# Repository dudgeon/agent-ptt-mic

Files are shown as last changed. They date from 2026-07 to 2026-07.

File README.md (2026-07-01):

# Claude Code Companion Peripheral

A single USB-C peripheral, built on a Seeed Studio XIAO RP2040, that
enumerates — with no driver install — as both a USB HID keyboard and a USB
Audio Class microphone at the same time. Physical controls handle push-to-talk
microphone activation, an always-on latch, and the keystrokes Claude Code uses
for its permission/approval prompts.

## Status

Pre-hardware-arrival, breadboard-planning phase. The RP2040 board has been
ordered but hasn't shipped yet. See [`docs/STATUS.md`](docs/STATUS.md) for the
live progress tracker.

## Start here

- [`docs/SPEC.md`](docs/SPEC.md) — the full project specification: verbatim
  requirements from the project owner, locked decisions, open questions, pin
  map, and the milestone-by-milestone work plan. This is the single source of
  truth; there is no other record of these requirements.
- [`docs/STATUS.md`](docs/STATUS.md) — current progress against the milestone
  plan and open questions.
- [`CLAUDE.md`](CLAUDE.md) — quick orientation for a coding agent picking this
  project up.

## Repo layout

```
docs/       spec + status
firmware/   RP2040 firmware (Pico SDK + TinyUSB)
hardware/   BOM, wiring notes, breadboard/PCB assets
```

## Hardware

- **MCU:** Seeed Studio XIAO RP2040 ([product page](https://www.seeedstudio.com/XIAO-RP2040-v1-0-p-5026.html), [wiki](https://wiki.seeedstudio.com/XIAO-RP2040/))
- **Mic:** I2S MEMS breakout (SPH0645 recommended, not yet purchased)
- **Controls:** 5 momentary buttons + 1 latching switch (see `docs/SPEC.md` §8 for the pin map)

## Work plan

See `docs/SPEC.md` §12 for the full milestone breakdown (M1–M7). In short:
toolchain bring-up → HID-only → UAC2-only (synthetic tone) → composite
HID+UAC2 device (highest-risk step) → real mic → buttons/gating/LED →
freeze for custom PCB handoff.

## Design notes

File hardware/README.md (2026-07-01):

# Hardware

Breadboard phase — see `docs/SPEC.md` §7 (BOM) and §8 (pin map).

## Bill of materials

| Part | Status |
|---|---|
| Seeed Studio XIAO RP2040 | Ordered, not arrived |
| I2S MEMS mic (SPH0645 recommended) | Not yet purchased (OQ2) |
| 5× tactile momentary switches | Not yet purchased |
| 1× slide/toggle switch (always-stream latch) | Not yet purchased |
| Breadboard + jumper wires | Not yet purchased |
| Data-capable USB-C cable | Not yet purchased |

## Pin map

See `docs/SPEC.md` §8 for the full XIAO-pad-to-GPIO table and the
constraints driving it (consecutive-GPIO requirement for I2S BCLK/LRCLK,
active-low buttons via internal pull-ups, active-low onboard LEDs).

This directory will hold breadboard photos, wiring notes, and eventually
custom PCB design files once the Milestone 7 gate (`docs/SPEC.md` §12) is
reached — no PCB work before then.

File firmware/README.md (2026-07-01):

# Firmware

Empty for now — no toolchain has been installed or firmware written yet.
This directory is scaffolding for Milestone 1 onward (see `docs/SPEC.md` §12).

## Planned toolchain (OQ1, proposed default)

**Pico SDK (C) + TinyUSB**, per `docs/SPEC.md` §5 OQ1. This is where the
reference USB Audio Class examples live (`uac2_headset`, `audio_4_channel_mic`)
and gives direct control over the composite USB descriptor needed for M4.
Not yet explicitly re-confirmed by the project owner — flagged in
`docs/STATUS.md`.

## Setup (once OQ1 is confirmed)

1. Install the [Pico SDK](https://github.com/raspberrypi/pico-sdk) and the
   `arm-none-eabi` toolchain.
2. TinyUSB is vendored as a submodule of the Pico SDK — no separate install.
3. Project layout will follow the standard Pico SDK CMake structure
   (`CMakeLists.txt` + `pico_sdk_import.cmake` at this directory's root).

None of this requires the physical board to be in hand — only flashing and
enumeration testing (M1's gate onward) do.

## Milestone-to-code mapping (planned)

- `m1_blink/` — minimal blink to prove the toolchain and flashing process
- `m2_hid/` — HID keyboard only
- `m3_uac2/` — UAC2 mic only, synthetic sine tone
- `m4_composite/` — merged HID + UAC2 composite descriptor
- `m5_mic/` — real I2S mic via PIO
- `m6_controls/` — buttons, switch, gating logic, status LED

These don't exist yet; created as each milestone starts.

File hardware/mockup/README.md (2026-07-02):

# 3D mockup — integrated design, real component dimensions

Dimensionally representative assembly of the whole device: carrier PCB,
XIAO RP2040 module (header-mounted on the back, USB-C facing away into
the back shell), 5× Kailh Choc V1 switches + MBK-profile caps, PCM12SMTR
latch slide (knob through the right wall), an I2S mic breakout module
(front side), an addressable RGB LED (v2.1 — see
`docs/PHYSICAL_DESIGN_SPEC.md` §7 for why it's SMD again), and both shell
halves. Every envelope comes
from `../design_params.py` — the same values that drive the PCB and
enclosure, so the mockup can't silently disagree with them.

Render-color note: the PTT cap is shown orange purely so reviews can point
at it; the real build is all-blank caps per the minimalist decision.

## Files

- `mockup.py` — builds all parts, exports `output/mockup_assembly.step`
  (colored STEP; open in any CAD viewer) and `output/parts/*.stl`.
- `render.py` — shades the part meshes and writes `output/renders/*.png`:
  assembled front/rear iso, internals front/back, orthographic front view,
  exploded view.

```
python3 hardware/mockup/mockup.py && python3 hardware/mockup/render.py
```

Outputs are committed for review without tooling.

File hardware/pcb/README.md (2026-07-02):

# Carrier PCB — KiCad project

2-layer carrier board (44 × 104 mm) for the handheld device: hosts the XIAO
RP2040 module (**pre-soldered/header SKU**, mounted on the BACK via its own
header pins, USB-C facing away into the back shell), 5× Kailh Choc V1
keyswitches, the PCM12SMTR side-actuated latch slide, an I2S mic
**breakout module** (front side, THT header), an **addressable RGB LED**
(WS2812B/SK6812-style — the one deliberately-reintroduced SMD part, see
below) + THT passives — every other active part is through-hole/header-
mount, hand-solderable with a plain iron (2026-07-02 revision; see
`docs/PHYSICAL_DESIGN_SPEC.md` §7 for why). Net/pin assignments follow
`docs/SPEC.md` §8 plus the status LED on spare D10/GPIO3 — the full
netlist table is in `../BOM.md`.

**Why the LED is SMD again:** Geoff asked for a true RGB status LED. A
discrete (non-addressable) RGB LED needs 3 independent GPIOs; the locked
pin map only has 2 spares. An addressable LED needs just 1 data pin, so
it's the only option that fits — still hand-solderable (large gull-wing
pads), just not through-hole.

## Files

- `generate_pcb.py` — the source of truth. Regenerates the board file from
  `../design_params.py`. Run `python3 hardware/pcb/generate_pcb.py` from the
  repo root after changing any dimension or position.
- `companion_carrier.kicad_pcb` — generated output (committed so it can be
  reviewed/opened without running anything).
- `companion_carrier.kicad_pro` — project file.

## Status: placed + netlisted, NOT routed

Deliberate scope cut, not an oversight: every footprint is placed and every
pad carries its net (open the board in KiCad and the full ratsnest appears),
but copper traces are not laid. Hand-computing trace geometry outside KiCad
means no live DRC, which is how you ship shorts. Routing this board in an
interactive KiCad session is ~30 minutes of work: all signals are slow
single-ended GPIO, the only mild care point is keeping the three I2S lines
short-ish and away from the LED data line. GND zones on both layers are
declared (fill them with `B` in pcbnew).

There is intentionally no `.kicad_sch`: the circuit is 17 components with a
one-net-per-switch topology, fully specified by the netlist table in
`../BOM.md` and encoded on the pads here. Drawing a schematic in KiCad from
that table is mechanical; hand-writing `.kicad_sch` s-expressions without
KiCad available to validate them is where errors would creep in.

## Before fabrication — VERIFY list

Footprint geometry here is derived from datasheets/community footprints at
design time. Before generating gerbers:

1. **XIAO header pin holes** — drill/pad size (currently 1.0mm drill,
   1.8mm pad) must fit the actual presoldered pin diameter; check against
   the physical board, not just a generic 0.1" header assumption.
2. **XIAO pin order** — the module is placed USB-down, back side; the
   pad-to-net map in `generate_pcb.py` encodes the 180° rotation of
   Seeed's USB-up pinout drawing. Sanity-check against a physical board
   before soldering.
3. **XIAO standoff/pin length** — `design_params.py XIAO_MODULE_STANDOFF`
   (6.0mm) is an estimate for how far the module hangs off the carrier;
   measure the real pin length before finalizing the enclosure thickness.
4. **PCM12SMTR land pattern** — approximated; pull the real drawing from the
   C&K datasheet.
5. **Mic breakout footprint** — `MIC_BRK_L/W` and pin pitch are
   approximate; measure the physical breakout (Adafruit #3421 or
   equivalent) and adjust before finalizing the front-wall window size.
6. **Choc contact-pin handedness** — pin 2 at (5.0, −3.8) assumes the common
   variant; check against a physical switch.
7. Run DRC after routing, obviously.

## Coordinate convention

Board space: X = 0 at the board centreline, Y = 0 at the top (mic) edge,
+Y toward the USB-C end. Sheet offset (60, 30) mm. All positions come from
`../design_params.py` — edit there, not here.

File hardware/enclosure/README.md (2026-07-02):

# Enclosure — FDM-printable handheld shell

Two printed parts (CadQuery source: `enclosure.py`, all dimensions from
`../design_params.py`):

- **Front shell** — front face + full-depth perimeter walls. Openings: one
  shared macropad-style cutout for the 2×2 keystroke cluster, a separate
  framed opening for the PTT key, a windowed opening sized to the mic
  breakout module and a ⌀3.4mm LED window at the top, latch-slide slot in
  the right wall, USB-C opening in the bottom wall (now much deeper in Z,
  since the module hangs off the back — see below). Four internal bosses
  locate and seat the PCB.
- **Back lid** — flush inset panel with four spacer bosses. M2 × 16
  self-tapping screws enter from the back: lid → spacer → PCB → front boss.

Envelope: **49.2 × 109.2 × 22.6 mm** — palm-sized vertical remote, thicker
than the original 14.3mm estimate. That growth is a direct, deliberate
consequence of the 2026-07-02 mounting revision: the XIAO Geoff actually
ordered is the pre-soldered/header SKU, which mounts on the carrier's BACK
via its own header pins rather than sitting flush — the `BACK_GAP` needed
to clear the module (module standoff + PCB + USB-C) grew from 3.2mm to
11.5mm. See `docs/PHYSICAL_DESIGN_SPEC.md` §7. The grip zone (blank lower
third of the front face) is where the XIAO hangs off the back; thumb lands
on PTT at bottom-centre with the 2×2 cluster above it.

## Regenerating

```
python3 hardware/enclosure/enclosure.py   # writes output/*.stl + *.step
```

`output/` is committed so the parts can be reviewed/printed without running
anything.

## Print notes

- Front shell prints face-down: clean front surface, walls/bosses grow
  upward, no supports; the USB and slide openings in the walls are small
  self-supporting bridges.
- Lid prints flat, boss side up.
- Sharp front edges: the parametric edge-break fillet is currently skipped
  (the CAD kernel refuses the fillet where opening rims meet the corner
  radii — logged at build time). For the fit-check print, break edges in
  the slicer or with sandpaper; a proper chamfer is a v2 modelling task.
- Flat, uninterrupted faces above/below/beside each opening are deliberate:
  they're the UV-print label zones per `docs/PHYSICAL_DESIGN_SPEC.md` §1.

## Fit-check before trusting the model

First print should verify: keycap free travel in the openings (0.5 mm/side
clearance), USB-C plug insertion depth through the 2.6 mm wall, slide-knob
reach through the right wall, and M2 self-tap engagement in the ⌀1.7 pilots.
Adjust `design_params.py` clearances and regenerate rather than editing
geometry by hand.

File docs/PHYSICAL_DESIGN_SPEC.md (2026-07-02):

# Physical Design Spec — PCB Breakout, Enclosure, and 3D Mockup

**Status:** Requirements captured 2026-07-01; first full design pass executed
2026-07-02 — see §7 for what was built and where the implementation deviated
from the proposals below.
**Scope note:** This track was explicitly requested by Geoff ahead of the
`docs/SPEC.md` §12 Milestone 7 gate ("no PCB work until the breadboard design
is functionally locked"). Per that document's own tie-breaker rule — a direct
instruction from Geoff overrides a locked decision — this is intentional and
tracked here rather than silently overriding §3.4. The breadboard milestone
plan (M1–M6) is unaffected and continues in parallel; this document covers a
second, concurrent track: selecting exact components and designing the
custom carrier PCB + handheld enclosure + a dimensionally-accurate 3D mockup.

This document is the handoff input for that second track. It captures the
decisions gathered directly from Geoff plus the engineering conclusions that
follow from them. **It does not contain finished component picks, PCB
layout, or 3D files** — those are the next session's deliverables (see
`docs/HANDOFF.md`).

---

## 1. Decisions gathered from Geoff (this session)

| Question | Answer |
|---|---|
| Form factor / mounting | **Handheld remote** — small enough to hold in one hand like a clicker, cable-tethered (not a desk puck, not keyboard/monitor-mounted). |
| Button tactile feel | **Mechanical keyswitches** — real switch mechanism with removable keycaps, not membrane/rubber-dome or bare SMD tactile buttons. |
| Enclosure fabrication | **3D printed, FDM** — desktop/service FDM printing, not resin/SLA, not laser-cut, not an off-the-shelf box. |
| Aesthetic / legends | **Minimalist** — clean, unlabeled surfaces. Geoff intends to add labels/graphics himself via **UV printing** onto the finished case after fabrication. The enclosure design must therefore leave flat, uninterrupted print-friendly surfaces near each control rather than integrating engraved/backlit legends. |

---

## 2. Engineering implications and proposed follow-ons [PROPOSED — confirm during next session or at the next checkpoint with Geoff]

These follow directly from the answers above but weren't asked explicitly —
flagging each rather than silently deciding.

### 2.1 Mechanical keyswitches in a handheld form factor → low-profile switch family
A **full-height Cherry MX-style switch** (~11mm switch body + ~7–8mm keycap
≈ 18–20mm stack height) makes for a thick, chunky handheld object — closer to
a game controller than a clicker. Given "handheld remote" was the explicit
form-factor choice, **low-profile mechanical switches** better satisfy both
answers at once:
- **Kailh Choc (PG1350, V1)** — ~11mm × 13.8mm footprint, ~2.6mm actuation
  travel, low-profile keycaps available (Choc/MBK caps), hot-swap sockets
  exist. Widely used in slim mechanical keyboards; well-documented KiCad
  footprints exist in community libraries.
- **Cherry MX Low Profile (RGB / Speed)** — same MX-compatible mount pattern
  as standard MX but ~11.9mm total height instead of ~18mm+; standard MX
  low-profile keycaps required (not interchangeable with full MX caps).
- **Recommendation for next session:** default to Kailh Choc V1 unless the
  next session's part-availability check favors Cherry MX Low Profile —
  Choc has the smaller footprint of the two, which matters more for a
  one-hand device.

### 2.2 The always-stream latch is a different control class than the 5 momentary buttons
A latching "always-stream" control shouldn't use a momentary keyswitch (it
would need firmware-side toggle logic and risks feeling wrong under the
thumb). Propose a small **mechanical slide or toggle switch** (e.g. C&K
sub-mini slide switch, or E-Switch EG-series toggle) as a genuinely distinct
part and physical affordance from the 5 keyswitches — so it's
unmistakable by feel alone which control is the latch.

### 2.3 Proposed control layout (handheld, one-hand operation)
No handedness preference was captured — proposing a **symmetric/ambidextrous**
layout as the default; flag for confirmation once a hand-sized mockup exists
and can be test-gripped.

- **Front face (thumb cluster):** the 4 keystroke buttons (Approve /
  Approve+Remember / Reject / Mode-toggle) arranged in a diamond, similar to
  a game-controller face-button cluster — reachable by thumb without
  regripping.
- **Top edge (index-finger position):** push-to-talk as a trigger/bumper-style
  control — distinct motion (squeeze vs. thumb-press) reduces the chance of
  confusing it with the keystroke buttons under stress.
- **Side of the shell:** the always-stream latch switch, positioned off the
  primary grip line to reduce accidental toggling.
- **Bottom edge:** USB-C cable exit + strain relief, so the cable trails away
  from the hand naturally during use.
- **Status LED:** the XIAO's onboard NeoPixel, either exposed directly at the
  top of the shell or routed to the surface via a small light pipe — final
  approach depends on where the module ends up sitting inside the shell.

### 2.4 USB-C: reuse the XIAO module's own connector, don't add a second one
The XIAO RP2040 module already has a USB-C connector on it. Recommend
mounting the module at the shell's edge so **its own connector is exposed
through a single cutout**, rather than adding a second USB-C connector to
the carrier PCB and re-routing D+/D− across a board-to-board connection —
simpler and removes a class of signal-integrity risk for no benefit here.

### 2.5 Microphone: place the bare SMD part on the carrier PCB, not a breakout module
`docs/SPEC.md` OQ2 recommends the SPH0645LM4H as a breakout board (Adafruit
#3421) for the breadboard track, which is still correct for M5. For the
custom-PCB track, since we're now doing SMD placement anyway, recommend
laying out the **bare SPH0645LM4H-B SMD MEMS mic package directly on the
carrier PCB** instead of mounting a separate breakout — matches the "PCB
breakout board that will take the SMD components" framing of this request.
This requires the enclosure's sound port hole to align to wherever the
carrier PCB places the mic (top-port vs. bottom-port orientation must be
confirmed against the current SPH0645LM4H datasheet next session — Adafruit's
breakout silkscreen is not a reliable substitute for the bare-part datasheet
here).

---

## 3. PCB breakout board — requirements for next session

1. **Carries the XIAO RP2040 module directly**, soldered via its castellated
   edge pads (per `docs/SPEC.md` §14 — the module is designed to be
   reflow/hand-soldered onto a carrier, no components populated on its
   underside). Source the module's real footprint from Seeed's official
   KiCad/Eagle library rather than hand-deriving pad positions from the wiki
   pinout diagram.
2. **Board outline is driven by the enclosure**, not the other way around —
   the handheld shell's internal cavity (from Section 4 below) sets the PCB's
   maximum size, not vice versa.
3. **2-layer PCB** is very likely sufficient — no high-speed routing beyond
   what the XIAO module already handles internally; carrier traces are just
   GPIO-to-switch and GPIO/PIO-to-mic.
4. **Switch footprints:** source real KiCad footprints for the chosen
   keyswitch family (Section 2.1) and the latch switch (Section 2.2) from
   community or manufacturer libraries — don't hand-derive from datasheet
   dimensions if a verified footprint already exists.
5. **Mic:** bare SPH0645LM4H-B SMD footprint per Section 2.5, oriented to
   match the enclosure sound port.
6. **Mounting:** holes/standoff positions matched to the enclosure design
   (Section 4) — coordinate the two designs together rather than sequentially.
7. **Design tool:** not yet chosen — recommend KiCad (free, scriptable,
   widely supported footprint libraries) unless the next session has a
   reason to prefer something else.

---

## 4. Enclosure — requirements for next session

1. **Form factor:** handheld remote, roughly clicker/game-controller sized —
   final dimensions driven by the keyswitch cluster footprint (2.1, 2.3) plus
   hand-fit margin, not chosen independently.
2. **Fabrication target: FDM 3D printing.** Design with FDM constraints in
   mind: minimum wall thickness for the printer/material in use (verify, but
   ~1.5–2mm is a reasonable starting assumption), avoid unsupported overhangs
   beyond ~45°, avoid features that require supports inside tight cavities
   (e.g., the switch/keycap openings).
3. **Split-shell design** (top/bottom halves, screwed or snap-fit together)
   for printability and access to the PCB/wiring — a one-piece shell isn't
   FDM-friendly for something this complex.
4. **Surfaces left flat and unadorned** near each control, sized to
   accommodate UV-printed labels/graphics added after fabrication (Section 1)
   — no engraved or backlit legends designed in.
5. **Cutouts:** USB-C connector (Section 2.4), mic sound port (Section 2.5),
   keyswitch openings sized to the chosen switch/keycap family, status LED
   window or light pipe.
6. **Strain relief** at the cable exit point.
7. **Deliverable format:** parametric/code-based CAD (OpenSCAD, CadQuery, or
   build123d) is strongly preferred over a GUI-only tool — it's versionable
   in this repo and an agent can iterate on it directly. STL for
   print-testing, STEP if a GUI tool is used for any part of the process.

---

## 5. 3D mockup — requirements for next session

The mockup must be **dimensionally accurate to the actual selected
components**, not placeholder blocks:
- Real XIAO RP2040 module footprint and height (including USB-C connector
  position on the module itself).
- Real keyswitch body dimensions and keycap profile for whichever family is
  selected (2.1).
- Real latch switch dimensions (2.2).
- Real SPH0645LM4H-B package dimensions and port location (2.5).
- Carrier PCB thickness (standard 1.6mm unless a reason emerges to change it).

Pull every dimension from the current datasheet/footprint library for the
part actually selected — do not carry forward a dimension from an earlier
guess without re-checking it against source data, since component picks in
Section 2 are proposals, not final.

---

## 6. What this document deliberately does not do

- Does not change the breadboard-track BOM in `docs/SPEC.md` §7 or the M1–M7
  milestone plan — those continue independently on the original hardware
  (Adafruit SPH0645 breakout, no custom PCB) until the M7 gate.

(As of 2026-07-02, part numbers, PCB files, CAD files and STL/STEP output
DO exist — see §7. The sections above are kept as the requirements record.)

---

## 7. Implemented design — 2026-07-02 session

The design pass described in `docs/HANDOFF.md` was executed. Artifacts:

- **Locked part picks + carrier netlist:** `hardware/BOM.md`.
- **Shared dimensional source of truth:** `hardware/design_params.py` — the
  PCB generator, enclosure CAD, and mockup all import from it.
- **Carrier PCB (KiCad):** `hardware/pcb/` — placed + netlisted, not yet
  routed (deliberate; see that README's rationale and pre-fab VERIFY list).
- **Enclosure (CadQuery → STL/STEP):** `hardware/enclosure/` —
  49.2 × 109.2 × 14.3 mm handheld, front shell + inset back lid.
- **3D mockup + renders:** `hardware/mockup/` — full colored STEP assembly
  and PNG views, every component at its datasheet envelope.

### Deviations from §2's proposals [PROPOSED — flag to Geoff]

1. **Keyswitch family: Kailh Choc V1** (per §2.1's default). Full-height MX
   was not pursued — it would push shell thickness past 20 mm.
2. **Keystroke cluster is a 2×2 grid, not a diamond** (§2.3 proposed a
   diamond). At Choc spacing a diamond spans ~54 mm — wider than a
   comfortable one-hand shell; the 2×2 grid keeps the device at 49 mm wide.
3. **PTT is a thumb key at bottom-centre, not an index-finger trigger on
   the top edge** (§2.3 proposed a trigger). An edge-mounted keyswitch
   needs a right-angle daughterboard — real complexity for v1. The PTT key
   sits where the thumb naturally rests when the lower third of the shell
   (the blank grip zone, XIAO inside) is in the palm. Revisit as a v2
   refinement if hold-to-talk by thumb proves fatiguing.
4. **Always-stream latch: C&K PCM12SMTR** right-angle slide at the right
   board edge, knob through the side wall — implements §2.2/§2.3 as
   proposed. (Left-handers: it's reachable but less convenient; symmetric
   it is not. Flag with the layout confirmation.)
5. **Status LED: WS2812B on the carrier at the top-front, driven from
   spare D10/GPIO3.** The XIAO's own NeoPixel ends up inside the closed
   shell at the bottom, so a carrier LED behind a ⌀2.5 window replaces it.
   One spare GPIO (D9) remains.
6. **The 2×2 cluster shares one front-face opening** (macropad-style
   bezel): at standard Choc pitch, per-key openings would leave <1 mm FDM
   walls between caps, which would not survive printing or use.

### v2 revision — mounting overhaul (2026-07-02)

Geoff pointed out the design had more SMD scope than the project actually
needs: the XIAO already carries all the real complexity (RP2040, USB,
flash), so this board should be "just a breakout for switches and a mic
module" — and separately confirmed the XIAO he ordered is the
**pre-soldered/header** SKU (`docs/SPEC.md` §4), which changes how it
physically mounts. Both points landed as one revision:

- **XIAO mounting:** was flush-reflow via castellated edges (assumed the
  bare SKU); now header-pin mounted on the carrier's **back**, since the
  pre-soldered module's pins need standoff clearance, not a flush joint.
  Its own presoldered pins pass through the carrier and solder there — no
  separate header/socket part needed. This is the dominant driver of the
  enclosure thickness change below.
- **Mic:** back to a breakout **module** (matching the original
  breadboard-track part) instead of a bare SMD chip — Geoff's original
  plan called for a module, and the bare-chip choice was this session's
  invention, not a requirement.
- **Status LED:** swapped from the addressable SMD WS2812B to a plain THT
  LED + resistor, per Geoff's explicit "keep it, but make it simple THT"
  — firmware now just drives GPIO3 high/low instead of bit-banging WS2812
  timing.
- **Passives:** switched from 0603 SMD to THT (ceramic disc caps, axial
  resistor) for consistency — no reason to leave fine-pitch SMD on an
  otherwise all-THT board.

**Net result:** every active component is now through-hole or header-mount
— hand-solderable with a plain iron, no reflow/hot-air required anywhere.
**Trade-off:** the enclosure grew from ~14.3mm to **~22.6mm thick**, since
the header-mounted module needs real standoff clearance (`BACK_GAP` went
from 3.2mm to 11.5mm) instead of sitting flush. This is a direct,
unavoidable consequence of the mounting method, not a modeling choice —
flagged here because it changes the device's hand-feel from "slim
clicker" toward "chunkier remote," which is worth Geoff being aware of
even though it wasn't separately asked about.

**Open follow-on, not yet resolved:** the vendor-sourcing research in
`hardware/ASSEMBLY_SOURCING.md` was done against the *v1* (bare-SMD/
flush-mount) design, where the XIAO module had its own JLCPCB
assembly-library listing implying automated placement. That listing was
almost certainly for the bare/castellated SKU meant for reflow — a
header-pin module standing off the board isn't a typical
pick-and-place/wave-solder candidate, so full vendor turnkey (zero solder
for *every* part, including the module) is now doubtful. The switches,
mic breakout, and LED/passives are still ordinary THT vendor-assembly
work; the XIAO itself (14 big, easy pins) may end up being the one thing
still worth self-soldering even in an otherwise-turnkey order. Tracked as
issue #15, and re-verified/resolved in the v2.1 cost-research pass below.

### v2.1 revision — RGB status LED, addressable after all (same day)

Geoff asked for the status LED to be RGB "for future status options,"
noting it doesn't need to be addressable. Implementing it surfaced a real
constraint: a genuine discrete RGB LED needs 3 independent GPIOs (separate
R/G/B anodes), and the locked pin map (`docs/SPEC.md` §8) assigns 9 of the
XIAO's 11 edge-pad GPIOs, leaving only 2 spares (D9, D10) — one short, and
no multiplexing trick closes that gap (charlieplexing only saves pins when
LED count exceeds pin count, which isn't the case for a single 3-channel
part). Asked Geoff to pick between three resolutions (addressable LED,
freeing a 3rd pin from the locked map, or dropping to 2-channel color);
**addressable LED was chosen.**

D1 is now a WS2812B/SK6812-style addressable RGB LED again, on the single
GPIO (D10) the budget actually has spare. This is the one deliberately
reintroduced SMD part on the board — still hand-solderable (large
gull-wing pads, not a reflow-only part like the v1 bare mic chip), and
firmware only needs to emit solid colors, not run animations, per Geoff's
"doesn't need to be addressable" (read here as "isn't a requirement," not
"must not be used" — it turned out to be the only option that fit the pin
budget). See `hardware/BOM.md` for the updated part/netlist and
`hardware/ASSEMBLY_SOURCING.md` for the re-run vendor/cost research this
prompted.

### Handoff, 2026-07-02: local research pass (pricing, sourcing, SW6)

This session's cost/sourcing research (`hardware/ASSEMBLY_SOURCING.md`)
was built entirely from search-snippet triangulation — no live browser
access, every direct vendor/distributor page fetch returned HTTP 403. That
research surfaced a real finding (the SW6 latch switch, C&K PCM12SMTR, is
listed Obsolete) that exposed a bigger gap: no part in `hardware/BOM.md`
was ever compared against real alternatives before being written down.
The whole BOM is now explicitly marked provisional, and the project has
been handed off to a local agent session with real browser access to do
that deeper survey — see `docs/HANDOFF.md` for full scope, with the SW6
component survey (issue #16) as the flagship task. Nothing in this
section should be read as final until that pass reports back.

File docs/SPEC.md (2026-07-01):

# Claude Code Companion Peripheral — Project Specification

**Status:** Pre-hardware-arrival, breadboard-planning phase
**Prepared for:** Handoff to a coding agent starting with no prior context
**Prepared:** July 1, 2026 (conversation-derived; verify time-sensitive facts before acting)

---

## 0. How to use this document

This is the single source of truth for a hardware/firmware project that began as a conversation and has **no other record**. Sections are labeled by confidence:

- **[LOCKED]** — explicitly decided by the project owner (Geoff). Do not revisit without asking.
- **[PROPOSED]** — recommended by the prior design conversation, not yet explicitly re-confirmed in the owner's own words. Treat as the working default, but flag it back to Geoff at the first natural checkpoint rather than silently assuming it's final.
- **[OPEN]** — a real decision point that has not been made. Blocks or partially blocks specific milestones (noted).

If you are the coding agent picking this up: read Sections 3–5 first (verbatims, locked decisions, open questions) before touching anything else. Section 12 is the actual work plan.

---

## 1. Project summary

A single custom hardware peripheral that plugs into a computer over one USB-C cable and — **without installing any driver** — is recognized simultaneously as a USB keyboard (HID) and a USB microphone. It has physical controls for: activating/deactivating the microphone, latching the microphone to always-on, and sending the keystrokes Claude Code uses for its permission/approval prompts. The goal is a tactile, dedicated control surface for voice input and approval-flow control while running Claude Code, rather than doing both through the host keyboard.

---

## 2. Customer verbatims (Geoff, in original order)

These are exact quotes from the project owner, preserved verbatim because they are the ground truth for requirements. Anything in this spec that isn't traceable to one of these (or to an explicit follow-up decision) is Claude's inference and is labeled as such.

**Message 1 (initial ask):**
> "I have a new idea for a project: a single peripheral that plugs into my computer via usb c and is recognized, without drivers, as both a keyboard and a microphone.
>
> This device has a small number of buttons, all three are programmable:
> - one activates the microphone, streaming audio to the computer
> - one is a switch, that sets the microphone to always stream
> - the remaining buttons are used to send the keystroke(s) that Claude code uses to receive approvals for actions, plans, etc (we may need a few of these if the different approval states requires keyboard shortcuts — I want to cover all of the most common)
>
> What is the minimal hardware board that can achieve these things? I am open to a custom pcb (you would design it) or a programmable microcontroller.
>
> The no driver requirement is hard, as is the single usbc plug for power and data."

**Message 2:**
> "Please give me links to the parts and verify the exact live bindings for Claude code shortcuts"

**Message 3:**
> "I'm going to go with the Seeed Studio XIAO RP2040 (adafruit option not available)
>
> There are so few visible I/o contacts; how do we handle all of the button io? Are there breakout boards available? Would we make a custom pcb for breakout?"

**Message 4:**
> "We will go with preordered and breadboard for now, and make a custom pcb once the design is locked.
>
> What's next?"

**Message 5 (this handoff request):**
> "Please give me a detailed write up of the project requirements including customer verbatims (mine) and locked decisions (eg the board I bought but has not arrived) and the work to be done. Spec is for handoff to coding agent to continue the project and will be a fresh start so it needs to be ultra detailed — if you miss details here they will be lost forever."

**Note on Message 1's button count:** Geoff wrote "all three are programmable" but then listed what reads as more than three physical items (one mic-activate button, one always-stream switch, and "the remaining button**s**" plural for keystrokes — implying more than one keystroke button). This spec interprets "three" as three *categories* of control (activate / latch / keystroke-send), not a literal cap of three physical buttons, and a follow-up design pass (Section 8) landed on 6 physical controls total. **This interpretation has not been explicitly re-confirmed by Geoff — flag it back to him.**

---

## 3. Locked decisions [LOCKED]

1. **Board: Seeed Studio XIAO RP2040.** Geoff has already ordered this board. **It has not yet arrived.** No further board-selection work is needed or wanted — do not revisit this choice.
   - Product family page: https://www.seeedstudio.com/XIAO-RP2040-v1-0-p-5026.html
   - Wiki/reference: https://wiki.seeedstudio.com/XIAO-RP2040/
   - The Adafruit QT Py RP2040 (functionally similar) was the original recommendation but was unavailable to purchase at decision time; the XIAO RP2040 was chosen as the in-stock equivalent.

2. **No-driver requirement is hard.** The device must enumerate using only classes natively supported by the OS out of the box: USB HID (keyboard) and USB Audio Class (microphone). No custom driver, kernel extension, or install step is acceptable on any target OS.

3. **Single USB-C connector for both power and data is hard.** No separate power jack, no battery in the current design, no second cable. Bus-powered only.

4. **Prototyping sequence:** breadboard the pre-ordered XIAO RP2040 first; **do not start custom PCB layout until the breadboard design is functionally locked** (Section 12, Milestone 7 gate).

5. **Composite USB device:** the single physical peripheral must present as *both* a keyboard and a microphone at the same time over the same port — not a switchable mode, not two cables, not a hub with two separate devices (a hub-based fallback was discussed as a hardware de-risking option in early exploration but is superseded now that the XIAO RP2040 module path was chosen — see Section 14).

6. **Privacy-preserving mic design pattern:** the USB Audio microphone interface should stay continuously enumerated at the USB level. Whether the host actually receives real audio or silence is gated in firmware by the physical push-to-talk / always-stream controls — not by dis/re-enumerating the USB interface. This was an explicit design goal from the original exploration (a hardware-enforced guarantee that nothing can be secretly listening unless a physical control is engaged) and should be preserved in implementation.

---

## 4. Board arrival — action items when it lands [OPEN, blocks Milestone 1]

Geoff ordered the board but it has not arrived as of this spec's writing. **Before starting firmware bring-up, confirm:**

- **Which SKU/variant actually shipped.** Seeed sells at least two relevant variants:
  - Headers included, unsoldered: https://www.seeedstudio.com/XIAO-RP2040-v1-0-p-5026.html
  - Pre-soldered (pins already attached, ready for breadboard): https://www.seeedstudio.com/Seeed-Studio-XIAO-RP2040-Pre-Soldered-p-6333.html
  - **This matters immediately**: a bare/header-included board needs the header strip soldered on before it can go into a breadboard at all. If the unsoldered variant arrived, soldering headers is the literal first physical step, before any firmware work.
- Visually confirm the board is the RP2040 variant (not a different XIAO family member — Seeed's XIAO line includes SAMD21, nRF52840, ESP32-S3, MG24, and others with different pinouts and capabilities; only the RP2040 variant matches everything in this spec).

---

## 5. Open decisions [OPEN — resolve before/during the listed milestone]

| # | Decision | Recommended default | Blocks | Owner |
|---|---|---|---|---|
| OQ1 | Firmware toolchain: **Pico SDK (C) + TinyUSB** vs. **Arduino + Adafruit TinyUSB core** | Pico SDK + TinyUSB — this is where the reference USB-Audio-Class mic examples live (`uac2_headset`, `audio_4_channel_mic`) and gives direct control over the composite USB descriptor. Arduino is a lighter option for HID-only experiments but is thinner on audio-class support. **CircuitPython is ruled out** — it has excellent HID support but does not expose a USB Audio Class device at all, so it cannot satisfy the microphone half of the requirement. | Milestone 1 (can't start without this) | Geoff / engineering |
| OQ2 | Microphone part — not yet purchased | SPH0645LM4H I2S MEMS mic, Adafruit #3421 (https://www.adafruit.com/product/3421). Alternative: ICS-43434, Adafruit #6049 (https://www.adafruit.com/product/6049) — note Adafruit's own listing states the ICS43434 has been discontinued and the SPH0645 is a drop-in replacement, so SPH0645 is the safer buy. Budget/no-link-verified alternative: INMP441 modules (widely available, same I2S interface). | Milestone 5 only (M1–M4 use a synthetic tone, no physical mic needed) | Geoff |
| OQ3 | Claude Code keystroke targeting strategy | See Section 10 for full detail. Two options: (a) hardcode the current default prompt keys (`1`/`Enter`, `2`, `Esc`, `Shift+Tab`) — simplest, but Claude Code ships weekly and default bindings have changed before; or (b) have the device target a **custom, explicit keybindings.json** config that Geoff installs once via Claude Code's own `/keybindings` command — more setup, but immune to upstream default-binding drift. **Not resolved; recommend (b) for durability but flag the extra one-time setup cost.** | Milestone 6 | Geoff / engineering |
| OQ4 | Behavior when push-to-talk *and* always-stream are both active simultaneously | Proposed: always-stream takes priority (mic stays live regardless of push-to-talk state). Not yet confirmed. | Milestone 6 | Engineering |
| OQ5 | What exactly fills the audio buffer when the mic is gated "off" — literal digital silence vs. low-level comfort noise | Proposed: literal silence (all-zero samples) unless testing reveals a host/app-side issue with dead air. | Milestone 5–6 | Engineering |
| OQ6 | Which operating systems must be validated for the "no drivers" requirement | Geoff's own machine is confirmed relevant (macOS, based on prior context). Whether Windows and/or Linux validation is required for this specific personal device is **not confirmed** — do not assume a broader deployment audience (e.g. Geoff's work context involves a large population of PMs, but nothing in this conversation ties this specific peripheral to that population). Ask before investing in multi-OS test rigs. | Milestone 4 | Geoff |
| OQ7 | Plan-mode approval (a multi-option menu, not a simple yes/no — see Section 10) currently has no dedicated button | Proposed: not needed for v1; the existing "Approve" button sending `Enter` will select whatever option is highlighted as default. Revisit if that proves insufficient in practice. | Not blocking; noted so it isn't lost | Geoff |

---

## 6. Non-goals (inferred, not explicitly confirmed — flag to Geoff)

To prevent scope creep during implementation, the following are assumed **out of scope** for this build unless Geoff says otherwise. None of these were explicitly ruled out or in — they are Claude's inference from "a single peripheral... single usbc plug":

- No wireless/Bluetooth connectivity.
- No on-device display or screen.
- No on-device storage or logging of audio/transcripts.
- No wake-word or on-device speech processing — the device is a dumb audio pipe; all intelligence is on the host.
- No support for pairing with multiple hosts simultaneously.
- No battery/portable power (explicitly ruled out by the "single USB-C for power and data" hard constraint).

---

## 7. Hardware bill of materials

### Locked / in hand (pending arrival)
| Part | Status | Link |
|---|---|---|
| Seeed Studio XIAO RP2040 | **[LOCKED]** Ordered, not arrived. Variant (pre-soldered vs. headers) unconfirmed — see Section 4. | https://www.seeedstudio.com/XIAO-RP2040-v1-0-p-5026.html |

### Needed, not yet purchased
| Part | Purpose | Recommended link |
|---|---|---|
| I2S MEMS microphone breakout | Audio input | SPH0645: https://www.adafruit.com/product/3421 |
| 4× tactile momentary switches | Approve / Approve+remember / Reject / Mode-toggle buttons, plus push-to-talk (5 total momentary, see pin map) | Commodity part, no SKU chosen |
| 1× slide or toggle switch | Always-stream latch | Commodity part, no SKU chosen |
| Breadboard + jumper wires | Prototyping | N/A |
| USB-C cable (data-capable) | Programming/power during dev | N/A |

### Deferred to future PCB phase — not needed now
See Section 14. Do not purchase these yet.

---

## 8. Pin assignment map [PROPOSED — not yet re-confirmed by Geoff after board choice]

The XIAO RP2040 exposes 11 usable GPIO on its edge pads, labeled D0–D10 by Seeed. This project needs 9, leaving 2 spare. Confirmed pin-to-GPIO mapping (source: TinyGo board definition, cross-referenced with Seeed's own pinout docs):

| XIAO pad | RP2040 GPIO | Assigned function |
|---|---|---|
| D0 | GPIO26 | Push-to-talk button (momentary) |
| D1 | GPIO27 | Always-stream switch (latching) |
| D2 | GPIO28 | "Approve" button → sends `Enter` |
| D3 | GPIO29 | I2S data in (mic SD/DOUT) |
| D4 | GPIO6 | I2S bit clock (BCLK) |
| D5 | GPIO7 | I2S word-select / LRCLK |
| D6 | GPIO0 | "Approve + remember" button → sends `2` |
| D7 | GPIO1 | "Reject" button → sends `Esc` |
| D8 | GPIO2 | "Mode toggle" button → sends `Shift+Tab` |
| D9 | GPIO4 | Spare |
| D10 | GPIO3 | Spare |

**Hard constraint driving this layout:** the RP2040 has no dedicated I2S hardware peripheral — I2S is implemented via the PIO (programmable I/O) subsystem, and the standard RP2040 I2S libraries (MicroPython's `machine.I2S`, pico-extras) require **BCLK and LRCLK to be on consecutive GPIO numbers**. That's why BCLK/LRCLK landed on GPIO6/GPIO7 specifically rather than more "logical" adjacent D-pad numbers.

**Microphone SEL pin:** tie to GND to select the left channel (the SPH0645/ICS-43434 mono mics use this pin to choose which I2S channel slot they occupy; GND = left, VDD = right).

**Button/switch wiring convention:** use the RP2040's internal pull-up resistors on every button/switch GPIO; wire the other side of each switch to GND. This means all controls are **active-low** (GPIO reads LOW when pressed/engaged) and need no external resistors.

**Onboard LED reference** (fixed silicon pins, not on the edge pads — free to use for status indication):
- WS2812/NeoPixel RGB LED: GPIO12 (power/enable: GPIO11)
- Discrete user LED: red = GPIO17, green = GPIO16, blue = GPIO25
- **Important quirk (from Seeed's own wiki):** on the XIAO RP2040, these programmable LEDs are **active-low** — the pin must be pulled low to light the LED, which is the reverse of typical Arduino LED convention. Account for this or you'll ship an "always on except when active" status light by accident.

**Known coincidental pin overlaps with RP2040 default peripheral assignments** (not a conflict today, since none of these hardware peripherals are used, but relevant if the design grows):
- D2/D3 are the RP2040's conventional I2C0 SDA/SCL pins.
- D4/D5 are the conventional I2C1 SDA/SCL pins (already consumed here by I2S clocks).
- D6/D7 are the conventional UART0 TX/RX pins.
- D8/D9/D10 are the conventional SPI0 SCK/SDI/SDO pins.
- **None of this blocks the current design** since no I2C, UART, or SPI hardware peripheral is used. Flagging only so a future feature addition (e.g., an SPI debug display, or an I2C GPIO expander like an MCP23017 for more buttons) doesn't collide with an already-assigned pin without warning.
- **Debug tooling suggestion:** rather than reserving a UART pin pair for serial debug output, consider adding a third interface (USB CDC serial) inside the same composite USB descriptor alongside HID and UAC2. TinyUSB supports multi-interface composite devices, and this avoids consuming any GPIO for debug at all. Worth deciding during Milestone 1–2.

**Known board-level limitation (informational, not currently relevant):** Seeed's own documentation states the XIAO RP2040 cannot be connected to USB-C while a LiPo battery is also connected, for safety reasons. Not applicable to this design (bus-powered only, no battery), but worth knowing if a future revision considers battery backup.

---

## 9. USB device requirements

1. Device must enumerate as a **composite USB device** combining:
   - A USB HID keyboard interface (boot or report protocol)
   - A USB Audio Class 2.0 (UAC2) microphone interface
   - Combined properly via an **Interface Association Descriptor (IAD)** so the host OS binds its native HID driver to one function and its native audio driver to the other, without any custom driver.
2. Zero driver installation required on any tested OS — this is the core hard requirement from Message 1 and the highest-risk item in the whole project (see Section 13).
3. **USB Full-Speed (12 Mbps)** is sufficient bandwidth for mono or stereo 48kHz/16-bit audio; no need to target High-Speed USB.
4. Device is **bus-powered only** — no self-powered mode, draws power entirely from the host's VBUS over the single USB-C connector.
5. Reference firmware starting points (TinyUSB, bundled with the Pico SDK):
   - `uac2_headset` example
   - `audio_4_channel_mic` example
   - Both should be studied for descriptor structure before writing a custom composite descriptor.
6. **Firmware behavior for the privacy-preserving gating pattern** (see Locked Decision 6): the UAC2 interface should remain enumerated continuously once the device is plugged in. The push-to-talk button and always-stream switch control, at the firmware level, whether real ADC/PIO-sourced samples or silence are written into the isochronous IN endpoint's data. This should never involve tearing down and re-establishing the USB Audio interface.

---

## 10. Claude Code keybinding reference (verified against live docs at time of writing)

**Caveat up front, and this is important: Claude Code ships weekly, and the specifics below were verified via live documentation search at conversation time. Before finalizing the firmware's keystroke map, re-check current behavior at https://code.claude.com/docs/en/permission-modes and https://docs.claude.com — do not assume these bindings are still current by the time firmware is written, especially if there's been a gap of weeks or more.**

### Per-action approval prompt
The prompt shown for individual tool actions (Bash commands, file edits, web fetches, etc.) presents three numbered choices, with the first pre-highlighted as default:
1. Approve once.
2. Approve **and** add a persistent "don't ask again" rule (scope — local project / user / project — has varied across versions; check current behavior).
3. Reject and give Claude Code different instructions — this option is also reachable via the Escape key.

**Resulting keystrokes to emit:**
- Approve once → `Enter` (works because option 1 is the highlighted default) or literal `1`
- Approve + remember → `2`
- Reject → `Esc` (or `3`)

### Permission-mode cycling (separate from the above)
`Shift+Tab` cycles the *session-wide* autonomy mode: `default` → `acceptEdits` → `auto` (only appears if the account is eligible for auto mode) → `plan`. This is a different control from the per-action approve/reject prompt — it changes how many future prompts will even appear, rather than answering one prompt.

### Plan-mode approval (distinct multi-option menu, not simple yes/no)
When Claude Code has finished plan-mode research and proposes a plan, the prompt is a menu with multiple named options (approve-and-switch-to-auto, approve-and-accept-edits, approve-for-manual-review, or keep refining the plan) rather than a binary yes/no. Selection is by number key, with `Enter` selecting whichever option is currently the default. There's also a documented `Ctrl+G` shortcut to open the proposed plan in the user's default text editor for manual edits before proceeding. **No dedicated hardware button currently targets this menu** — see Open Question OQ7.

### Durability recommendation (see OQ3)
Claude Code also ships a formal **user-configurable keybinding system**: running `/keybindings` inside a session generates (or opens) `~/.claude/keybindings.json`, where individual actions in named "contexts" can be bound to specific key combinations, validated against a published JSON schema. Rather than hardcoding the current default prompt keys into this device's firmware, consider having the firmware target a small set of custom, unambiguous bindings that Geoff defines once in that config file — this would insulate the hardware from future changes to Claude Code's own defaults. This is a genuine open decision (OQ3), not a locked choice.

---

## 11. Firmware design requirements summary

- Language/stack: see OQ1 (unresolved).
- USB stack: TinyUSB (whichever wrapper — raw Pico SDK or Arduino core).
- Composite descriptor: HID keyboard interface + UAC2 microphone interface + IAD, optionally + USB CDC for debug (see Section 8 debug tooling note).
- Audio path: PIO-based I2S receive (no native I2S peripheral on RP2040) → gating logic (real samples vs. silence based on button/switch state) → UAC2 isochronous IN FIFO.
- Button/switch handling: internal pull-ups, active-low, software debounce, mapped per Section 8's pin table to the HID keystrokes in Section 10.
- Status indication: onboard NeoPixel/RGB LED reflects live mic-streaming state (remember the active-low LED-enable quirk noted in Section 8).
- Known component-level firmware risk: the SPH0645 mic's I2S output has documented quirks — it's left-justified with a bit-alignment offset from a "textbook" I2S stream, and it carries a DC offset that typically needs a high-pass/DC-blocking filter in firmware to avoid audible artifacts. Budget real debugging time for this at Milestone 5; verify against the current SPH0645 datasheet and community example code before assuming a specific fix.

---

## 12. Work breakdown / milestone plan

Work in this order. Each milestone has a hard pass/fail gate — do not proceed past a milestone whose gate hasn't been met, and do not skip ahead because a later milestone seems easier. The composite-USB-device milestone (M4) is the single highest-risk step in the whole project and should be treated as such.

### M1 — Toolchain bring-up
- Resolve OQ1 (firmware toolchain) if not already resolved.
- Install the chosen toolchain.
- Flash the XIAO RP2040 via its BOOTSEL bootloader (hold the BOOT button while connecting USB-C → board appears as a USB mass-storage drive → drag on a `.uf2` file) with a minimal program that blinks the onboard LED.
- Remember the active-low LED convention noted in Section 8.
- **Gate:** a self-built UF2 flashes successfully and the LED blinks at an interval set in your own source code (not a stock example you haven't modified).

### M2 — HID keyboard, standalone
- Build a minimal TinyUSB HID keyboard descriptor. No audio interface yet.
- Emit one test keystroke via a timer or a simple debug trigger.
- **Gate:** device enumerates as a standard keyboard on macOS with **zero driver prompts**, and the test keystroke lands in a text field.

### M3 — UAC2 microphone, standalone, synthetic audio
- Build a minimal TinyUSB UAC2 descriptor for a microphone-input-only device (mono or stereo, 48kHz/16-bit). No HID yet.
- Fill the isochronous IN FIFO with a firmware-generated sine wave — **no physical microphone wired yet.**
- **Gate:** device enumerates as an audio input device on macOS with zero driver prompts, and the tone is recordable in QuickTime or Audacity.

### M4 — Composite device: HID + UAC2 together — **highest-risk milestone**
- Merge M2 and M3 into a single composite descriptor using a correctly structured Interface Association Descriptor.
- **Gate:** a single physical device plugged into one USB-C port simultaneously shows up as *both* a keyboard and a microphone, with zero driver installation, on macOS at minimum (see OQ6 for whether Windows/Linux validation is in scope). This is the point where the core "single peripheral, both keyboard and mic, no drivers" requirement from Message 1 is proven at the protocol level.

### M5 — Real microphone integration
- Resolve OQ2 (purchase the mic breakout) if not already resolved.
- Breadboard-wire the mic per the Section 8 pin table (BCLK→D4, LRCLK→D5, SD→D3, SEL→GND).
- Implement PIO-based I2S receive on the RP2040 (there is no hardware I2S peripheral — this must go through PIO).
- Replace the synthetic tone from M3 with real mic samples.
- Address the SPH0645 bit-alignment/DC-offset quirks noted in Section 11.
- **Gate:** a recorded sample is intelligible speech, not noise, silence, or garbled audio.

### M6 — Buttons, switch, gating logic, and status LED
- Wire all 5 physical controls (push-to-talk, always-stream switch, and the 3 keystroke buttons... **note: Section 8's table has 4 keystroke buttons, not 3** — approve/approve+remember/reject/mode-toggle — reconcile this against Geoff's original "three buttons" framing per the note at the end of Section 2, and confirm the final control count with Geoff if it hasn't already been settled) per the Section 8 pin map, with internal pull-ups and software debounce.
- Implement push-to-talk gating: samples flow only while the button is held; released, silence flows (see OQ5 for exact silence behavior).
- Implement always-stream latch behavior, including the both-active edge case (OQ4).
- Wire the 4 keystroke buttons to their HID outputs per Section 10, resolving OQ3 (default-keys vs. custom keybindings.json) before finalizing.
- Drive the onboard RGB LED to reflect live mic state.
- **Gate:** a full end-to-end test inside a real Claude Code session — talk on push-to-talk and confirm the audio is received correctly by whatever app/service Claude Code routes it through; press each keystroke button and confirm the correct action occurs in a terminal that has focus.

### M7 — Polish and lock for PCB handoff
- Finalize debounce timings and the always-stream/push-to-talk interaction.
- Decide and implement key-repeat behavior (or explicit non-repeat) for the keystroke buttons.
- Freeze the pin map, parts list, and firmware behavior as the locked baseline.
- **Only after this gate is met:** begin custom PCB layout. PCB design is explicitly out of scope for this work breakdown — it is Geoff's stated next phase (Section 3, Locked Decision 4) and should be spec'd separately once M7 is reached.

---

## 13. Known technical risks

1. **UAC2 composite-descriptor firmware (M4)** is the single highest-risk item in the project — this was flagged as "the only genuinely fiddly bit" in the original design exploration. Everything else (buttons, I2S mic reads) is comparatively well-trodden ground.
2. **SPH0645 I2S output quirks** (bit alignment, DC offset) — budget real debugging time; don't assume a naive I2S read will produce clean audio.
3. **Claude Code keybinding drift** — the product ships weekly; hardcoded default keys may silently stop matching the live UI. See OQ3 and Section 10's durability recommendation.
4. **Board variant ambiguity** — don't assume the ordered XIAO RP2040 is breadboard-ready out of the box; confirm per Section 4 the moment it arrives.
5. **Two blocking open decisions gate the very first milestone**: OQ1 (toolchain) must be resolved before M1 can start at all.
6. **Scope of "no drivers"** — the hard requirement doesn't specify which OS(es); don't over- or under-invest in cross-platform testing without checking OQ6 with Geoff first.

---

## 14. Deferred: custom PCB phase (not in scope for current work)

Once the breadboard design is locked (M7 gate), Geoff's stated plan is a custom PCB — either carrying the XIAO RP2040 module itself (its castellated edge pads and "no components on the back" design mean it's meant to be reflow- or hand-soldered directly onto a carrier board) or, if the UAC2 firmware proves genuinely infeasible on the RP2040 module, a fallback path explored earlier in the design conversation using dedicated audio-class silicon instead of firmware-implemented USB Audio:

- Bare-chip alternative silicon (if ever needed): Raspberry Pi RP2354B — has 2MB of stacked flash on-package, avoiding an external QSPI flash chip. https://thepihut.com/products/raspberry-pi-rp2354b-microcontroller (also available via LCSC: https://www.lcsc.com/product-detail/C39843328.html)
- Hardware-audio-codec fallback (if firmware UAC2 proves too costly): TI PCM2902C class-compliant USB stereo audio codec (https://www.ti.com/product/PCM2902C) paired with a USB hub IC (e.g. Microchip USB2422) to combine it with a separate HID microcontroller behind one port. This path trades firmware risk for an analog mic input (rather than the digital I2S mic used in the current plan) and added board complexity — it is a fallback, not the current direction, and should only be revisited if M4 proves unworkable on the RP2040.

**This entire section is deprioritized and informational only** — the current locked path is the XIAO RP2040 module handling both HID and UAC2 in firmware. Do not start PCB or alternative-silicon work until Section 12's M7 gate is reached and Geoff explicitly asks for it.

---

## 15. Reference links (consolidated)

- Seeed XIAO RP2040 (headers): https://www.seeedstudio.com/XIAO-RP2040-v1-0-p-5026.html
- Seeed XIAO RP2040 (pre-soldered): https://www.seeedstudio.com/Seeed-Studio-XIAO-RP2040-Pre-Soldered-p-6333.html
- Seeed XIAO RP2040 wiki: https://wiki.seeedstudio.com/XIAO-RP2040/
- TinyGo XIAO RP2040 pin/peripheral reference: https://tinygo.org/docs/reference/microcontrollers/machine/xiao-rp2040/
- Seeed XIAO Expansion Base (prototyping aid, optional): https://www.seeedstudio.com/Seeeduino-XIAO-Expansion-board-p-4746.html
- Adafruit SPH0645 I2S MEMS mic: https://www.adafruit.com/product/3421
- Adafruit ICS-43434 I2S MEMS mic (discontinued per vendor): https://www.adafruit.com/product/6049
- Claude Code permission modes docs: https://code.claude.com/docs/en/permission-modes
- Claude Code approval-prompt UI reference (GitHub issue with live examples): https://github.com/anthropics/claude-code/issues/11073
- Anthropic engineering blog on Claude Code auto mode: https://www.anthropic.com/engineering/claude-code-auto-mode
- (Deferred/fallback) RP2354B: https://thepihut.com/products/raspberry-pi-rp2354b-microcontroller
- (Deferred/fallback) TI PCM2902C: https://www.ti.com/product/PCM2902C

---

## 16. Addendum: accelerated PCB / industrial-design track [LOCKED — explicit instruction from Geoff]

On 2026-07-01, Geoff explicitly asked to begin component selection, physical
layout, custom PCB breakout design, enclosure design, and a dimensionally
accurate 3D mockup — ahead of the Milestone 7 gate that Locked Decision 4
(Section 3) otherwise requires before any PCB work starts.

Per this document's own tie-breaker rule (see the closing line below), a
direct instruction from Geoff overrides a locked decision, so this is
intentional rather than scope creep. It does not cancel Locked Decision 4 or
the M1–M7 breadboard plan — it opens a **second, concurrent track** that
targets a custom PCB + handheld enclosure directly, using different (SMD)
components than the breadboard BOM in Section 7.

Full requirements, the physical/aesthetic decisions Geoff gave directly, and
the engineering follow-ons derived from them live in
`docs/PHYSICAL_DESIGN_SPEC.md`. Do not duplicate that content here — treat
this section as a pointer plus the record of the decision itself, so it
isn't lost the way this whole spec exists to prevent.

---

*End of spec. If anything in this document conflicts with a direct instruction from Geoff, his instruction wins — flag the conflict rather than silently resolving it.*

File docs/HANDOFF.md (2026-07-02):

# Handoff — Local Research Agent (Pricing/Sourcing/Component Refinement)

**Written:** 2026-07-02, end of a session that did PCB/enclosure/mockup
design work plus two rounds of vendor-cost research, entirely blocked from
live browser access — direct `WebFetch` of jlcpcb.com, pcbway.com, and
most distributor pages returned HTTP 403 every time, including inside an
automated deep-research workflow (21/21 source fetches failed on the
first attempt). Everything sourcing-related in this repo so far is built
from search-engine-indexed snippets, triangulated across many queries —
real, but weaker evidence than a live page load. **You have real browser
access this session. That's the entire reason for this handoff — use it.**

> ## Prompt used to resume this session
>
> Geoff pastes something close to this to kick off the local agent:
>
> > Continue the `agent-ptt-mic` hardware design track. Read
> > `docs/HANDOFF.md` in full before doing anything else — it has complete
> > context and scoped priorities from the previous session, which had no
> > live browser access (every direct fetch of jlcpcb.com/pcbway.com/
> > distributor pages was blocked). You have real browser access this
> > session — use it to get live quotes, check real stock/pricing, and
> > verify parts/footprints against primary sources instead of search
> > snippets.
> >
> > Priority #1: do a genuine component survey for the always-stream latch
> > switch (SW6). The current pick, C&K PCM12SMTR, is obsolete and was
> > never compared against any alternative — don't assume the SMT-slide-
> > switch category, or the C&K PCM series, is the only viable option.
> > Survey broadly against the actual requirement (see `docs/HANDOFF.md`
> > and `hardware/BOM.md`'s SW6 callout, and GitHub issue #16).
> >
> > Priority #2: re-verify the assembly-cost/sourcing findings in
> > `hardware/ASSEMBLY_SOURCING.md` (GitHub issue #15) with real quotes
> > instead of search snippets.
> >
> > This is a research and refinement pass, not a final-decision pass —
> > leave part/cost decisions open/provisional in the docs (matching the
> > repo's existing **[LOCKED]**/**[PROPOSED]** convention), cite live
> > sources for everything you find, and flag anything that needs Geoff's
> > sign-off rather than deciding for him. Commit and push your findings
> > when done.

## Ground rules

- **Leave decisions open.** `hardware/BOM.md` is explicitly marked
  provisional, not final. Your job is research and refinement: verify
  real prices/stock/footprints, survey alternatives, update docs with
  findings + citations. Don't quietly lock in final part picks — flag
  them for Geoff's confirmation the same way the rest of this repo
  distinguishes **[LOCKED]** from **[PROPOSED]** (see `docs/SPEC.md` §0's
  confidence-label convention, which applies everywhere in this repo).
- **Cite everything.** Every claim you add to `hardware/BOM.md` or
  `hardware/ASSEMBLY_SOURCING.md` should trace to a real URL you actually
  loaded, not a memory or a guess.
- **Don't order anything.** No fab, parts, or PCBA orders without Geoff's
  explicit go-ahead — standing rule, unchanged from every prior handoff
  in this repo.
- **Geoff won't see this session directly** — he's handing this off
  precisely to get a research pass done without spending his own time in
  the loop. Document thoroughly enough that he can review findings
  asynchronously rather than needing to ask you follow-up questions.

## Priority #1: the latch switch (SW6) — deep component survey

**This is the flagship task for this session.** The current pick (C&K
PCM12SMTR) turned out to be listed Obsolete by one distributor — but the
real problem it exposed is that **no alternative was ever surveyed**. Full
context, already written up in detail, is in:

- `hardware/BOM.md` — the expanded "⚠ SW6 (latch switch) — open gap"
  callout: the actual requirement traced to its source (Geoff only ever
  asked for "a switch that makes the mic always stream" — nothing about
  mechanical type, mounting, or manufacturer), what was this session's
  own inference vs. a real requirement, candidate categories nobody has
  compared yet, and filter criteria for a replacement.
- [GitHub issue #16](https://github.com/dudgeon/agent-ptt-mic/issues/16) —
  same content, durable tracking.

Don't just find a replacement part number — use your browser to actually
compare candidates (toggle switches, rocker switches, rotary-detent
switches, other manufacturers' slide switches, possibly a
magnetically-latched slider) against real stock/pricing/datasheets, and
weigh the momentary-button-with-firmware-latch alternative explicitly
(cheaper/simpler, but weakens the physical-state-visibility point behind
`docs/SPEC.md` §3 Locked Decision 6 — worth writing out for Geoff to
weigh in on, not deciding unilaterally). Leave the final pick flagged
**[PROPOSED]** unless Geoff has actually signed off.

## Priority #2: re-verify the v2.1 assembly-cost/sourcing research with real quotes

`hardware/ASSEMBLY_SOURCING.md` and `hardware/assembly_options.html` are
both built from search-snippet triangulation, explicitly caveated as
such. Real next step: get an actual JLCPCB instant quote and an actual
PCBWay quote (their consigned/combo parts flow specifically, per the
current doc's finding that PCBWay is more likely to accept the two
header-mounted modules as customer-supplied parts) using the real files
in this repo (`hardware/pcb/companion_carrier.kicad_pcb`, `hardware/BOM.md`).
Confirm or correct:

- Real PCB fab cost for a 44×104mm 2-layer board at qty 5
- Whether either vendor will actually place the XIAO module and the mic
  breakout module (both header-mounted, not simple components) — this is
  the one thing the previous session flagged as genuinely unconfirmable
  from search snippets alone
- Real per-unit pricing for the XIAO pre-soldered SKU and the mic
  breakout (both had wide, low-confidence price ranges in this round)
- Whether a manual-placement fee for the modules is reasonable or "massive"
  (an EEVblog thread title used exactly that word for a similar case —
  cited as a live warning in `hardware/ASSEMBLY_SOURCING.md`, not
  confirmed against this specific board)

Tracked as [GitHub issue #15](https://github.com/dudgeon/agent-ptt-mic/issues/15).
Update `hardware/assembly_options.html` (mobile-friendly HTML artifact,
built with the repo's `dataviz` skill conventions — see the file itself
for the CSS custom-property palette already in use, reuse it rather than
inventing a new one) once you have real numbers.

## Other open verification items (VERIFY tags scattered across the repo)

Every one of these needs a real datasheet or physical-part check, not
another round of search snippets:

- `hardware/design_params.py`: `XIAO_MODULE_STANDOFF` (header standoff
  gap, currently a typical-for-class estimate), `CHOC_PIN2` (contact pin
  handedness), `MIC_BRK_L`/`MIC_BRK_W` (breakout footprint dimensions),
  `SLIDE_*` constants (tied to SW6 above — will change once a replacement
  is picked).
- `hardware/pcb/generate_pcb.py`: XIAO pad geometry vs. Seeed's official
  footprint, the mic breakout header land pattern, the slide-switch land
  pattern (tied to SW6).
- `hardware/pcb/README.md` "Before fabrication — VERIFY list" — the
  consolidated version of the above, check it against this list for
  drift.

## Read first, in this order

1. This document, in full (you're doing that now).
2. `docs/STATUS.md` — current state of both project tracks (breadboard
   firmware + PCB/industrial-design).
3. `docs/PHYSICAL_DESIGN_SPEC.md` §7 — the full history of the physical
   design revisions (v2: header-mounted XIAO + mic breakout; v2.1: RGB
   LED forced addressable by the pin budget) and why each happened.
4. `hardware/BOM.md` — the provisional parts list, SW6 gap fully written up.
5. `hardware/ASSEMBLY_SOURCING.md` — existing cost/sourcing research,
   including its own "what changed since v1" section and method caveats.
6. `hardware/assembly_options.html` — open this in a real browser; it's
   the cost-comparison artifact Geoff has already seen.
7. GitHub issues #12–#16 — all open, all relevant to this pass.

## What's already decided (don't re-litigate without a real reason)

- Handheld remote form factor, cable-tethered, one-hand operation.
- Kailh Choc V1 low-profile mechanical keyswitches for the 5 momentary
  controls, blank MBK caps.
- XIAO RP2040, **pre-soldered/header SKU** (confirmed by Geoff directly,
  not inferred) — mounts on the carrier's back via its own header pins.
- Mic breakout module (not a bare chip) on the front, matching the
  original breadboard-track part family.
- Addressable RGB status LED — not because it needs to be addressable,
  but because the locked pin map (`docs/SPEC.md` §8) only has 1 spare
  GPIO after accounting for the LED, and discrete RGB needs 3. Geoff
  confirmed this resolution explicitly after being shown the constraint.
- FDM 3D printing as the enclosure fabrication target; minimalist,
  unlabeled surfaces (Geoff UV-prints labels himself post-fab).
- Every active component except the LED is through-hole/header-mount —
  hand-solderable with a plain iron, no reflow/hot-air needed anywhere.

**What's explicitly still open, not just the latch switch:** the whole
BOM is provisional (see the banner at the top of `hardware/BOM.md`).
Don't assume anything in that table is final just because it's written
down — that's exactly the trap SW6 fell into.

## Deliverables for this session

1. Deep component survey for SW6 (issue #16) with real candidates, real
   pricing/stock, and a clearly-flagged recommendation — not a final
   decision unless Geoff has signed off.
2. Live-quote-verified update to `hardware/ASSEMBLY_SOURCING.md` and
   `hardware/assembly_options.html` (issue #15).
3. Resolve as many `VERIFY` tags as practical with real sourced data;
   update `hardware/design_params.py` and regenerate the PCB/enclosure/
   mockup (`python3 hardware/pcb/generate_pcb.py`, `python3
   hardware/enclosure/enclosure.py`, `python3 hardware/mockup/mockup.py
   && python3 hardware/mockup/render.py`) if any dimension changes.
4. Update `docs/STATUS.md` and this document when done, same pattern as
   every prior session in this repo.

## Constraints carried over (still apply, unchanged)

- No driver install requirement, single USB-C for power+data, continuous
  UAC2 enumeration with firmware-side gating — electrical/firmware
  behavior is out of scope for this pass, only sourcing/component
  selection.
- Breadboard firmware track (M1–M7) is a separate, parallel effort — see
  `docs/STATUS.md`. Nothing in this handoff blocks or is blocked by it.

---

## Appendix: prior handoff (executed 2026-07-02, PCB/enclosure/mockup design pass)

<details>
<summary>Original handoff from the requirements-gathering session to the
design-execution session. All five scoped deliverables were completed —
kept here for the record, not as active instructions. Click to expand.</summary>

**Written:** 2026-07-01, end of the requirements-gathering session.
**Why this doc existed:** Geoff asked to hand the PCB/enclosure/mockup
track to a more capable model for execution. That session gathered
requirements and physical/aesthetic decisions; it deliberately stopped
short of doing the design work itself.

### Read first, in this order (original)

1. `docs/SPEC.md` §16 — records that this track was explicitly authorized
   by Geoff ahead of the normal Milestone 7 gate.
2. `docs/PHYSICAL_DESIGN_SPEC.md` — requirements: Geoff's answers, the
   engineering conclusions that follow, section-by-section requirements
   for the PCB, enclosure, and 3D mockup.
3. `docs/SPEC.md` §7, §8, §9, §11 — original electrical/firmware spec.

### What was decided (original)

- Handheld remote form factor, cable-tethered, one-hand operation.
- Mechanical keyswitches for the 5 momentary controls.
- A separate slide/toggle switch for the always-stream latch.
- FDM 3D printing as the fabrication target.
- Minimalist, unlabeled surfaces (UV-print labels post-fab).

### Scoped deliverables (original, all completed)

1. Finalize component part numbers.
2. PCB breakout design (KiCad).
3. Enclosure design (parametric CAD).
4. 3D mockup with real component dimensions.
5. Update `docs/STATUS.md`, open GitHub issues for anything left open.

All five were delivered — see `docs/PHYSICAL_DESIGN_SPEC.md` §7 for the
artifact map, deviations, and the two subsequent same-day revisions
(v2: mounting overhaul; v2.1: RGB LED) this produced.

</details>

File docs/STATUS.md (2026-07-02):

# Status

Live tracker — update this as work happens. `SPEC.md` is the frozen requirements
record; this file is the mutable "where are we right now."

**Last updated:** 2026-07-02

## Current phase

Two concurrent tracks:

1. **Breadboard firmware track (M1–M7, SPEC.md §12).** Pre-hardware-arrival —
   the Seeed Studio XIAO RP2040 has been ordered (see SPEC.md §3, §4) but has
   not arrived. No firmware milestone can be gated/verified on real hardware
   yet (flashing, enumeration checks, audio recording all require the board
   in hand).
2. **PCB / industrial-design track (SPEC.md §16).** Design spike Geoff
   requested while awaiting delivery; runs in parallel with (not instead of)
   the breadboard plan. **First full design pass complete (2026-07-02),
   then revised twice same day:** v2 (Geoff confirmed the XIAO he ordered is
   the **pre-soldered/header SKU** — answers issue #9 ahead of physical
   arrival, still worth a visual check on arrival that it's the RP2040
   family member — and asked to cut unnecessary SMD scope; every active
   part except the LED is now through-hole/header-mount, at the cost of a
   thicker enclosure, ~22.6mm vs. ~14.3mm) and v2.1 (Geoff asked for a true
   RGB status LED; the locked pin map only had 1 spare GPIO after the LED,
   so it reverted to addressable — Geoff confirmed this resolution). See
   `docs/PHYSICAL_DESIGN_SPEC.md` §7 for full rationale and remaining
   deviations awaiting Geoff's confirmation.

   **Two rounds of vendor-cost research done, both from search-snippet
   triangulation only** — this session had no live browser access
   (jlcpcb.com/pcbway.com/most distributor pages 403 every direct fetch).
   That research surfaced a real find (the SW6 latch switch, C&K
   PCM12SMTR, is listed Obsolete) that exposed a bigger gap: **no part in
   `hardware/BOM.md` has been compared against real alternatives** — it's
   explicitly marked provisional now, not final.

   **⏸ Handed off 2026-07-02 to a local agent session with real browser
   access** for a deeper research/refinement pass — see `docs/HANDOFF.md`
   for full scope (flagship task: SW6 component survey, issue #16;
   secondary: re-verify assembly costs with live quotes, issue #15).
   Decisions in `hardware/BOM.md` stay open/provisional until that pass
   reports back. Remaining after that: layout sign-off, PCB routing +
   pre-fab footprint verification, first fit-check print.

## Milestone progress (SPEC.md §12)

| Milestone | Gate | Status |
|---|---|---|
| M1 — Toolchain bring-up | Self-built UF2 flashes, LED blinks on custom timing | Not started — blocked on board arrival + OQ1 |
| M2 — HID keyboard standalone | Enumerates as keyboard, zero driver prompts, test keystroke lands | Not started |
| M3 — UAC2 mic standalone (synthetic tone) | Enumerates as audio input, tone recordable | Not started |
| M4 — Composite HID+UAC2 (highest risk) | Single device shows as both, zero drivers | Not started |
| M5 — Real mic integration | Recorded sample is intelligible speech | Not started — blocked on OQ2 (mic purchase) |
| M6 — Buttons/switch/gating/LED | End-to-end test inside real Claude Code session | Not started — blocked on OQ3/OQ4/OQ5 |
| M7 — Polish, freeze for PCB handoff | Pin map/parts/firmware frozen | Not started |

## What can happen before the board arrives

Firmware toolchain setup and skeleton project scaffolding don't require the
physical board — only flashing/testing does. See `firmware/README.md` for
current toolchain status.

## Open questions needing Geoff's input (SPEC.md §5)

- **OQ1** (blocks M1, [#2](https://github.com/dudgeon/agent-ptt-mic/issues/2)):
  toolchain — Pico SDK + TinyUSB vs. Arduino. Proceeding with Pico SDK +
  TinyUSB as the working default per the spec's own recommendation; flag for
  explicit confirmation.
- **OQ2** (blocks M5, [#3](https://github.com/dudgeon/agent-ptt-mic/issues/3)):
  mic part not yet purchased — SPH0645 (Adafruit #3421) recommended.
- **OQ3** (blocks M6, [#4](https://github.com/dudgeon/agent-ptt-mic/issues/4)):
  hardcode default Claude Code keys vs. target a custom `keybindings.json`.
- **OQ4** (blocks M6, [#5](https://github.com/dudgeon/agent-ptt-mic/issues/5)):
  push-to-talk + always-stream both active — proposed always-stream wins.
- **OQ5** (blocks M5/M6, [#6](https://github.com/dudgeon/agent-ptt-mic/issues/6)):
  silence vs. comfort noise when mic gated off.
- **OQ6** (blocks M4, [#7](https://github.com/dudgeon/agent-ptt-mic/issues/7)):
  which OSes need "no driver" validation beyond macOS.
- **OQ7** (non-blocking, [#8](https://github.com/dudgeon/agent-ptt-mic/issues/8)):
  no button for plan-mode's multi-option menu yet.
- **Board arrival checklist** (blocks M1, [#9](https://github.com/dudgeon/agent-ptt-mic/issues/9)):
  confirm SKU/variant the moment the XIAO RP2040 lands.
- **Button-count reconciliation** (blocks M6, [#10](https://github.com/dudgeon/agent-ptt-mic/issues/10)):
  "three buttons" verbatim vs. the 6-control pin map — not yet re-confirmed.

Milestone progress is also tracked as a checklist in
[#1](https://github.com/dudgeon/agent-ptt-mic/issues/1).

## Immediate next steps

### Breadboard track
1. Confirm OQ1 with Geoff (or proceed on the recommended default and flag it).
2. Set up Pico SDK + TinyUSB build environment (does not require the board).
3. When the board arrives: work through SPEC.md §4 / issue #9 (SKU/variant
   check) before anything else.
4. Purchase mic (OQ2) and buttons/switch (SPEC.md §7) — not urgent until M5/M6
   but lead time may be worth ordering now.

### PCB / industrial-design track
1. **Next up (handed off, see `docs/HANDOFF.md`):** local-agent research
   pass with real browser access — SW6 latch-switch component survey
   (issue #16, flagship task) and live-quote verification of the
   assembly-cost research (issue #15).
2. Geoff reviews the mockup renders (`hardware/mockup/output/renders/`) and
   confirms/adjusts the layout deviations in `docs/PHYSICAL_DESIGN_SPEC.md`
   §7 (thumb PTT, 2×2 grid, right-side latch) — independent of the
   research pass, can happen in parallel.
3. Route the carrier board in an interactive KiCad session and work the
   pre-fab VERIFY list in `hardware/pcb/README.md` — after the SW6
   footprint question (issue #16) resolves, since that switch's land
   pattern is one of the things being routed.
4. FDM fit-check print of the two shell parts (checklist at the end of
   `hardware/enclosure/README.md`). Ordering parts/fab needs Geoff's
   go-ahead first.

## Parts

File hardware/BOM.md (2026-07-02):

# Bill of Materials — Carrier PCB Track (v2.1)

> **Status: PROVISIONAL, not final.** Every part below was picked by an AI
> design session with no live browser access to distributor stock/pricing
> pages (see `hardware/ASSEMBLY_SOURCING.md`'s method note and
> `docs/HANDOFF.md`). Treat this whole table as a working draft pending a
> deeper pricing/availability review by a session with real browser
> access — **not** a locked parts list. SW6 below is the known example of
> why: a part picked here turned out to be obsolete, and it was never
> compared against alternatives in the first place. Assume other picks
> deserve the same scrutiny before ordering anything.

Provisional part selections for the custom carrier PCB + handheld
enclosure track (`docs/PHYSICAL_DESIGN_SPEC.md`). The breadboard track's
BOM in `docs/SPEC.md` §7 is separate and unchanged.

**v2 revision (2026-07-02):** the XIAO Geoff actually ordered is the
**pre-soldered/header** SKU (`docs/SPEC.md` §4), not the bare-castellated
one v1 assumed — it mounts via its own presoldered pin headers, not a
flush reflow joint. At the same time, the mic switched from a bare SMD
chip to a breakout module (matching the original breadboard-track part).
Net effect: the XIAO, mic, switches, and passives are all through-hole/
header-mount — hand-solderable with a plain iron, no reflow needed for
any of them — at the cost of a thicker enclosure (~22.6mm vs. ~14.3mm in
v1), since the header-mounted module needs real standoff clearance
instead of sitting flush.

**v2.1 revision (same day):** Geoff asked for the status LED to be RGB.
A genuine discrete RGB LED needs 3 independent GPIOs; the locked pin map
(`docs/SPEC.md` §8) only has 2 spares. Rather than touch the pin map, D1
reverts to an **addressable** RGB LED (WS2812B/SK6812-style) — the only
way to get full RGB from the one GPIO the budget actually has spare.
Firmware only needs to emit solid colors (no animation requirement), but
still has to speak the WS2812 protocol to do that. This is the one
deliberately-reintroduced SMD part on the board — still hand-solderable
(large gull-wing pads, not a reflow-only part like the old mic chip was).

See `hardware/assembly_options.html` for the cost/effort comparison this
enables (**pending a rebuild reflecting v2.1** — see
`docs/PHYSICAL_DESIGN_SPEC.md` §7 for the full rationale on both
revisions).

Per project convention: **verify availability and datasheet revisions before
placing any order** — and per `docs/HANDOFF.md`, don't order fab or parts
without checking with Geoff first.

## Electronics

| Ref | Qty | Part | Package / mount | Why this part | Source |
|---|---|---|---|---|---|
| U1 | 1 | Seeed Studio XIAO RP2040 — **pre-soldered** | Header pins, mounted on carrier BACK via its own presoldered pins pushed through + soldered | [LOCKED] board choice; module carries USB-C, RP2040, flash, NeoPixel | [Seeed, pre-soldered](https://www.seeedstudio.com/Seeed-Studio-XIAO-RP2040-Pre-Soldered-p-6333.html) |
| SW1–SW5 | 5 | Kailh Choc V1 (PG1350) — Brown/tactile suggested | Through-hole switch pins + locating posts | Low-profile mechanical keyswitch: real switch feel in a handheld-thickness shell (11 mm stack vs ~18.5 mm for full MX) | Kailh via distributors (Chosfox, splitkb, MoErgo, AliExpress) |
| — | 5 | MBK Choc-profile 1u keycaps, blank | Friction-fit on Choc stem | Blank per the minimalist/UV-print decision | Same suppliers as switches |
| SW6 | 1 | ~~C&K PCM12SMTR~~ slide switch (SPDT) — **⚠ OBSOLETE, see note** | Right-angle SMT, actuator past PCB edge | Latch control on the shell *side wall* per §2.3; distinct-by-feel from the keys. Kept SMD — ordinary hand-solder gull-wing pads, not a reflow-only part like the old mic chip, so no reason to swap the mounting style | [C&K/Littelfuse](https://www.ckswitches.com/products/switches/product-details/Slide/PCM/PCM12SMTR/), Digi-Key `CKN10361CT-ND` |
| MK1 | 1 | I2S MEMS mic **breakout module** (e.g. Adafruit SPH0645, PID 3421) | 6-pin THT header, front side, own onboard acoustic port | Matches the original breadboard-track part (SPEC §7 OQ2) instead of a bare reflow-only chip — hand-solderable header pins | [Adafruit #3421](https://www.adafruit.com/product/3421) |
| D1 | 1 | WS2812B (5050) or SK6812 addressable RGB LED | SMD, front side, top edge | v2.1: full RGB "for future status options," reintroduced as addressable because the pin budget only has 1 spare GPIO left (see revision note above) — driven with solid colors only, no animation requirement | Commodity |
| C1 | 1 | 100 nF THT ceramic disc | THT, 5mm lead spacing | Mic VDD decoupling | Commodity |
| C2 | 1 | 100 nF THT ceramic disc | THT, 5mm lead spacing | LED decoupling | Commodity |
| C3 | 1 | 10 µF THT electrolytic/ceramic | THT, 5mm lead spacing | Bulk for LED + mic rail | Commodity |
| R1 | 1 | 300–500 Ω 1/4W axial resistor | THT, formed leads | LED data-line series resistor (signal integrity, not current-limiting — WS2812 draws its own current) | Commodity |

> ## ⚠ SW6 (latch switch) — open gap, needs a deep component survey
>
> **This is flagged as a documentation task, not resolved here.** Found
> during the v2.1 cost-research pass (2026-07-02): Future Electronics
> lists the C&K PCM12SMTR as **Obsolete**. DigiKey still shows stock at
> $0.96/unit but with a "not recommended for new designs" style notice;
> RS Online and LCSC (`C221841`) still list it as orderable at this
> writing. That's a real, narrow supply-risk fact — but it surfaced a
> bigger problem worth stating plainly: **this part was never compared
> against any alternative.** It was the first plausible-looking part an
> AI design session found for the slot, not the result of a survey. It is
> not plausible that C&K PCM12SMTR is the *only* switch that can do this
> job — a proper survey almost certainly wasn't done, and needs to be.
>
> **The actual requirement, traced to its source, so the next session
> isn't guessing what SW6 is *for*:**
> - `docs/SPEC.md` §2, Message 1 (Geoff, verbatim, **[LOCKED]**): "...one
>   is a switch, that sets the microphone to always stream..." — this is
>   the *only* hard requirement. Geoff asked for **a switch** that makes
>   the mic always-stream. He did not specify mechanical type, mounting
>   style, or manufacturer.
> - `docs/SPEC.md` §3 Locked Decision 6 (privacy-preserving gating): the
>   always-stream control is one of the two physical inputs that gate
>   real-vs-silence audio in firmware — implying a **physical** control a
>   user can see/feel the state of, which is why a momentary button
>   pretending to be a toggle (state held only in firmware, no physical
>   position to check by eye or touch) is a weaker fit for the *spirit* of
>   that guarantee, even though it would satisfy the letter of §2. Worth
>   the next session weighing explicitly rather than defaulting to it for
>   convenience if bistable mechanical parts prove hard to source.
> - `docs/PHYSICAL_DESIGN_SPEC.md` §2.2 (this session's own inference,
>   **not** a Geoff requirement): "a genuinely distinct physical
>   affordance from the 5 keyswitches... unmistakable by feel alone which
>   control is the latch." This is where "must feel different from a
>   Kailh Choc key" came from — reasonable, but self-imposed, and worth
>   re-confirming rather than treating as locked.
> - Everything else about SW6 — SMT vs. THT, side-wall mounting, knob
>   protruding through a shell slot, the specific C&K PCM12 *series* —
>   was this session's mounting proposal (§2.2/§2.3), not a requirement.
>   **The next session should not treat "SMT slide switch" as the
>   category to search within.** Legitimate alternative categories,
>   none yet surveyed: panel/PCB-mount mini toggle switches, rocker
>   switches, rotary switches with a detent, other manufacturers'
>   ultraminiature slide switches (Omron, Alps Alpine, TE Connectivity,
>   Panasonic — not just C&K), or a magnetically-latched slider. A
>   capacitive/touch control with firmware-held state is also technically
>   possible but weakens the physical-state-visibility point above —
>   flag it as an option, don't default to it.
>
> **Filter criteria for a replacement, once real candidates are found:**
> mechanically bistable (holds position without power) preferred over
> momentary+firmware-latch; hand-solderable without reflow (SMT gull-wing
> or THT both fine — the whole board moved to hand-solderable parts this
> session, don't reintroduce a reflow-only part); tactilely distinct from
> the Kailh Choc keys; fits or reasonably re-shapes the shell's side-wall
> slot (`hardware/design_params.py` `SLIDE_*` constants — these can move
> if a better part needs a different envelope, the enclosure isn't fixed
> around this one part); **active production, in stock at 2+ independent
> distributors**, given what just happened with PCM12SMTR.
>
> Tracked as [GitHub issue #16](https://github.com/dudgeon/agent-ptt-mic/issues/16)
> (updated with this framing) and flagged as the priority item in
> `docs/HANDOFF.md` for the next session. Footprint/pin spacing in
> `hardware/pcb/generate_pcb.py` (`slide_pcm12()`) and the `SLIDE_*`
> constants in `hardware/design_params.py` will need updating once a
> replacement is actually chosen — don't do that yet, the survey comes
> first.

Optional (decided against for v2, easy to add later): Kailh Choc hot-swap
sockets (CPG135001S30) — v2 solders switches directly for simplicity and
lower back-side height.

**Superseded from v1** (kept here for history, not for ordering): Knowles
SPH0645LM4H-B bare SMD chip, 0603 SMD passives.
**Superseded from v2** (briefly, same day): plain 3mm THT LED — reverted
to addressable in v2.1 per the pin-budget constraint above.

## Enclosure hardware

| Qty | Part | Purpose |
|---|---|---|
| 4 | M2 × 16 mm self-tapping screws | Back lid → spacer boss → PCB → front-shell boss (stack now ≈ 2 + 11.5 + 1.6 mm + ~4 mm thread engagement, up from the v1 flush-mount stack — the header-mounted module pushed BACK_GAP out to 11.5mm) |
| 1 | FDM print, 2 parts (front + back shell) | `hardware/enclosure/` outputs |

## Electrical connections (carrier netlist summary)

Pin assignments preserve `docs/SPEC.md` §8 exactly; the only addition is the
status LED on previously-spare D10.

| XIAO pad | GPIO | Net | Connects to |
|---|---|---|---|
| D0 | GPIO26 | `PTT` | SW5 (push-to-talk key) → GND |
| D1 | GPIO27 | `LATCH` | SW6 (slide) common → GND |
| D2 | GPIO28 | `KEY_APPROVE` | SW1 → GND |
| D3 | GPIO29 | `I2S_SD` | MK1 DATA |
| D4 | GPIO6 | `I2S_BCLK` | MK1 BCLK |
| D5 | GPIO7 | `I2S_LRCLK` | MK1 WS/LRCLK |
| D6 | GPIO0 | `KEY_REMEMBER` | SW2 → GND |
| D7 | GPIO1 | `KEY_REJECT` | SW3 → GND |
| D8 | GPIO2 | `KEY_MODE` | SW4 → GND |
| D9 | GPIO4 | spare | — |
| D10 | GPIO3 | `LED_DATA` | R1 → `LED_DIN` → D1 DIN |
| 3V3 | — | `3V3` | MK1 VDD, D1 VDD, C1–C3 |
| GND | — | `GND` | all switches, MK1 GND + SEL (left ch.), D1 GND |

Note on the LED (v2.1): D1 is addressable (WS2812B/SK6812-style), so
GPIO3 carries the WS2812 single-wire data protocol through R1 to DIN, not
a simple high/low current-limited drive. D1's DOUT is left unconnected
(not chained to a second LED). WS2812B is a 5V part that generally runs
fine at 3.3V with a 3.3V data signal; swap to SK6812 (native 3.3V) if
brightness/reliability disappoints. All button/switch inputs use the
RP2040 internal pull-ups, active-low, no external resistors (SPEC §8
convention).

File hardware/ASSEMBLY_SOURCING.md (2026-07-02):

# Assembly sourcing — JLCPCB vs PCBWay (zero-solder feasibility)

**Current as of:** 2026-07-02, v2.1 BOM (pre-soldered/header XIAO, mic
breakout module, addressable RGB LED — see `hardware/BOM.md`). Supersedes
the v1 research kept as an appendix at the bottom of this file.

**Method note, both rounds:** direct `WebFetch` of jlcpcb.com and
pcbway.com pages returns HTTP 403 (bot-blocked) every time, including
inside the automated deep-research workflow (21/21 sources failed there
on the first pass). This round is built from ~14 targeted `WebSearch`
queries against search-engine-indexed snippets — including community/
forum sources (EEVblog, Deskthority, Hackaday.io) alongside vendor pages
— triangulated across independent queries per claim. Treat anything not
phrased as "confirmed" as needing a live quote-tool check, not settled
fact.

## What changed since the v1 research

The v1 BOM had a bare SMD mic chip and a single-color LED — nothing that
looked like a genuine "module." The v2.1 BOM has **two actual modules**
sitting on header pins (the XIAO itself, and the mic breakout), and
that's a fundamentally different sourcing question than "is this
component in a vendor's parts library" — assembly houses' pick-and-place
equipment is built to place discrete components fed from tape/reel/tray,
not whole daughterboard modules standing off on their own header pins.
That reframes the whole "zero solder" question.

## Headline finding: JLCPCB vs. PCBWay diverge on customer-supplied parts

- **JLCPCB:** "generally does not accept customer-supplied components for
  their standard assembly service, to maintain quality control and
  component traceability." Their help-center consignment articles
  (`how-to-consign-parts-to-jlcpcb`, `consignment-part-terms-conditions`)
  exist, but read as a separate, more manual process — not part of the
  self-service instant-quote flow most small orders use.
- **PCBWay:** explicitly supports **Kitted/Consigned** (customer supplies
  all parts) and **Combo** (customer supplies some, PCBWay sources the
  rest) as first-class order types, with published rules for how
  customer-supplied parts must be packaged (reeled/taped, minimum
  quantities per package type).

**This flips last round's lean.** With a BOM that's mostly discrete
components, JLCPCB's "everything's already in our library" story won out.
With two actual modules that need to be supplied by the customer either
way, PCBWay's willingness to accept consigned parts as a matter of
routine process is the more relevant capability — *if* an assembly
house's manual-placement fee for something as tall/irregular as these
modules doesn't erase the benefit (see the EEVblog "massive manual
assembly fee" thread referenced in the Q&A below; nobody should assume
this is cheap without a real quote).

## Q&A summary (v2.1 BOM)

1. **Can either vendor place the XIAO or the mic breakout module?**
   Uncertain, and this is the crux of the whole question. JLCPCB's
   standard flow likely declines (no customer-supplied parts outside
   their library). PCBWay's consigned/combo flow is built for exactly
   this case in principle, but a header-pin module standing several mm
   off the board is still an irregular-placement item — JLCPCB's own
   fee schedule for "components that cannot be picked up by machines"
   ($0.0157/pin manual-placement fee, "may increase if difficult") shows
   this class of part is treated as an exception even when accepted, not
   routine. Needs a real quote from PCBWay to know if they'll even take
   the job, and at what fee.
2. **THT soldering (switches, passives).** Both vendors offer wave/
   selective-soldering for through-hole parts as a paid add-on
   (JLCPCB: ~$3.50 flat hand-soldering labor + ~$0.0135–0.0173/joint) —
   this part of the finding is unchanged from v1 and still solid: the 5
   keyswitches, the passives, and (if a replacement part is picked, see
   below) the latch switch are all ordinary vendor-assemblable work.
3. **LED in-library:** WS2812B confirmed cheap and widely stocked —
   LCSC lists Worldsemi WS2812B variants at $0.03–0.05/unit in reel
   quantities; expect more like $0.30–0.60/unit for small hobbyist
   quantities from Amazon/AliExpress-style sellers.
4. **Part risk found this round, not previously flagged:** the C&K
   PCM12SMTR slide switch (SW6, the latch) is listed **Obsolete** by
   Future Electronics. DigiKey/RS Online/LCSC still show it orderable at
   this writing, but it's not a part to build a long-term footprint
   around — tracked as issue #16.
5. **MOQ/pricing, updated for this board's real footprint:** the carrier
   is 44×104mm — over JLCPCB's "$2-for-5-boards under 100×100mm" bracket
   (104mm exceeds the 100mm side), so PCB fab alone likely runs
   somewhere in the $8–20/5-boards range rather than the headline $2,
   though an exact figure needs the live quote tool. PCBA setup+stencil
   minimums cluster around $30–70 for a double-sided board at JLCPCB
   (one referenced July-2025 example: $33.66 minimum for single-sided
   Economic PCBA setup+stencil alone, before parts/labor). PCBWay's
   often-cited "$5 for 5-10 boards" figure is PCB fab only, not PCBA —
   don't conflate the two when reading vendor marketing pages.
6. **Whole-device, one vendor:** unchanged from v1 — JLCPCB+JLC3DP have a
   documented combined-order flow; PCBWay offers the same service breadth
   but combined ordering leans on contacting their sales team.
7. **Updated small-parts pricing (informs the cost artifact):**
   - XIAO RP2040, pre-soldered: ~£19 (~$24) at UK retail (Amazon.co.uk);
     US pricing likely somewhat lower direct from Seeed — verify before
     ordering, regional/retailer price spread is wide for this part.
   - Mic breakout (Adafruit SPH0645 #3421 or equivalent): $14.73 at
     Walmart in this search; Adafruit's own direct-list price is
     typically lower (historically ~$6–8) — use a range, reseller
     markup varies a lot for this part.
   - Kailh Choc V1 switches: no clean per-unit bulk price surfaced;
     community pricing knowledge puts these around $0.60–0.90/switch in
     small quantities.
   - MBK blank keycaps: €0.85/cap individually (42Keebs) down to about
     €0.69/cap in 10-packs (Keycapsss) — roughly $0.75–0.95/cap in USD.
   - C&K PCM12SMTR (if bought now, before obsolescence bites): $0.96 at
     DigiKey, $0.66–1.18 across other distributors.

## Bottom line

**Neither vendor gives a confident "yes, fully zero-solder" answer for
this BOM** the way v1's research suggested — the two modules are the
open question, and it genuinely depends on getting a real quote (likely
from PCBWay, given their consigned-parts process) rather than something
resolvable from search snippets. What *is* solid: the 5 keyswitches, the
passives, and the LED are all routine vendor-assemblable work at either
shop, and — the more important practical point — **hand-soldering the
two modules yourself is not the hard problem it used to be.** In the v1
BOM, "solder it yourself" meant reflow/hot-air for an LGA mic chip with
no accessible leads. In v2.1, both modules are big, friendly through-hole
header pins (14 + 6 = 20 joints, no fine pitch, no reflow) — genuinely
one of the easier parts of this build. That changes the cost-options
framing in `hardware/assembly_options.html`: full DIY is now realistic
for far more people than it was under the old BOM, and the "pay a vendor"
case rests on convenience/time, not on a skill/tooling barrier the way it
did before.

## Before committing to an order

Get a real PCBWay quote for the consigned/combo path (with the two
modules called out explicitly) before assuming either "zero solder" or
"vendor won't touch it" — this is the one thing search snippets
genuinely can't settle. Resolve the SW6 obsolescence (issue #16) before
finalizing any BOM for ordering. Per `docs/HANDOFF.md`'s standing rule:
no fab/parts order without Geoff's go-ahead.

---

## Appendix: v1 research (superseded, kept for the record)

<details>
<summary>Original 2026-07-02 findings, built against the bare-SMD-mic /
flush-mount XIAO / addressable-LED-that-was-later-dropped-then-restored
BOM. Click to expand.</summary>

Every part in the v1 BOM already had a JLCPCB assembly-library listing,
including the XIAO RP2040 module itself:

| Part | JLCPCB part # | Status |
|---|---|---|
| Seeed XIAO RP2040 module (bare/castellated) | C9900176459 | "New Arrivals" category; listing notes it needs an assembly fixture |
| Kailh Choc 1350 keyswitch | C9900088831 | "New Arrivals" category |
| C&K PCM12SMTR slide switch | C221841 | established catalog listing |
| Knowles SPH0645LM4H-B mic (bare chip) | C2686054 | established catalog listing |
| WS2812B LED | C2761795 (Worldsemi WS2812B_BT) | established catalog listing |

That listing was almost certainly for the *bare/castellated* XIAO SKU
meant for reflow — which turned out not to be the SKU Geoff actually
ordered, so this specific conclusion didn't carry forward. JLCPCB Economic
vs. Standard PCBA tier rules, THT wave-soldering costs, and MOQ figures
from that round are still accurate and repeated in the current findings
above where still applicable.

</details>

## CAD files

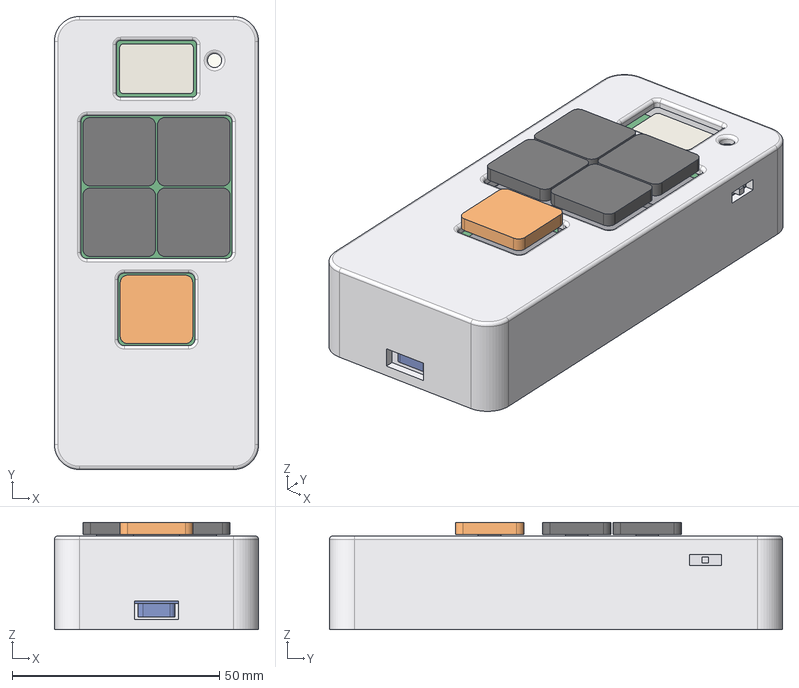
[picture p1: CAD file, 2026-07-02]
hardware/mockup/output/mockup_assembly.step
49.2 x 109.2 x 25.9 mm
pcb
switch_approve
cap_approve
switch_remember
cap_remember
switch_reject
cap_reject
switch_mode
cap_mode
switch_ptt
cap_ptt
xiao
slide
mic
led
front_shell
back_lid

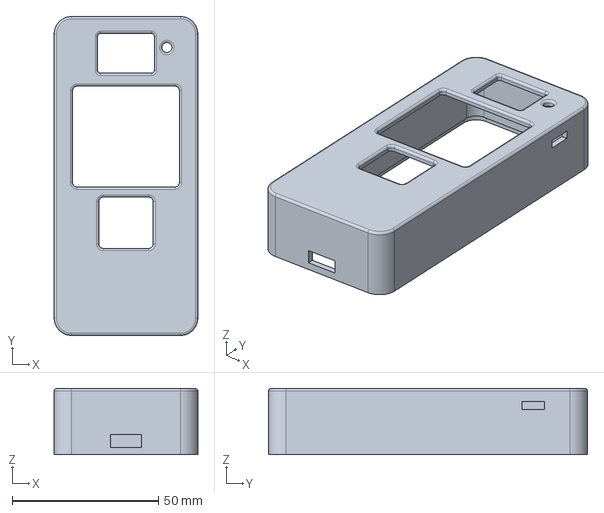
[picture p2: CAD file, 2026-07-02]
hardware/enclosure/output/front_shell.step
49.2 x 109.2 x 22.6 mm

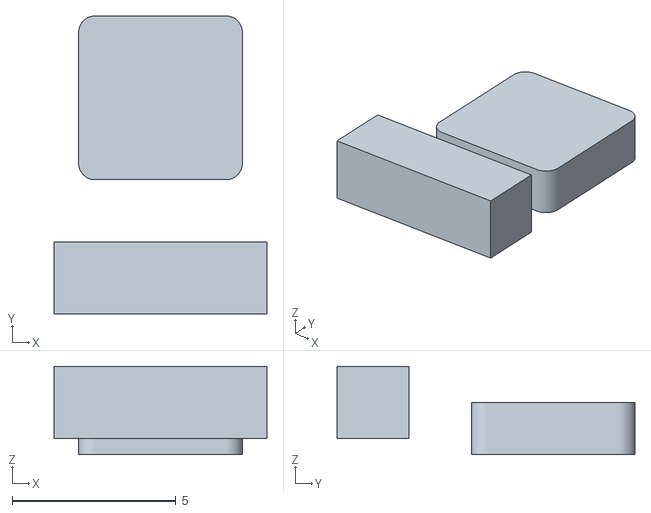
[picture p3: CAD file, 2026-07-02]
hardware/mockup/output/parts/led.stl
6.50 x 9.10 x 2.70

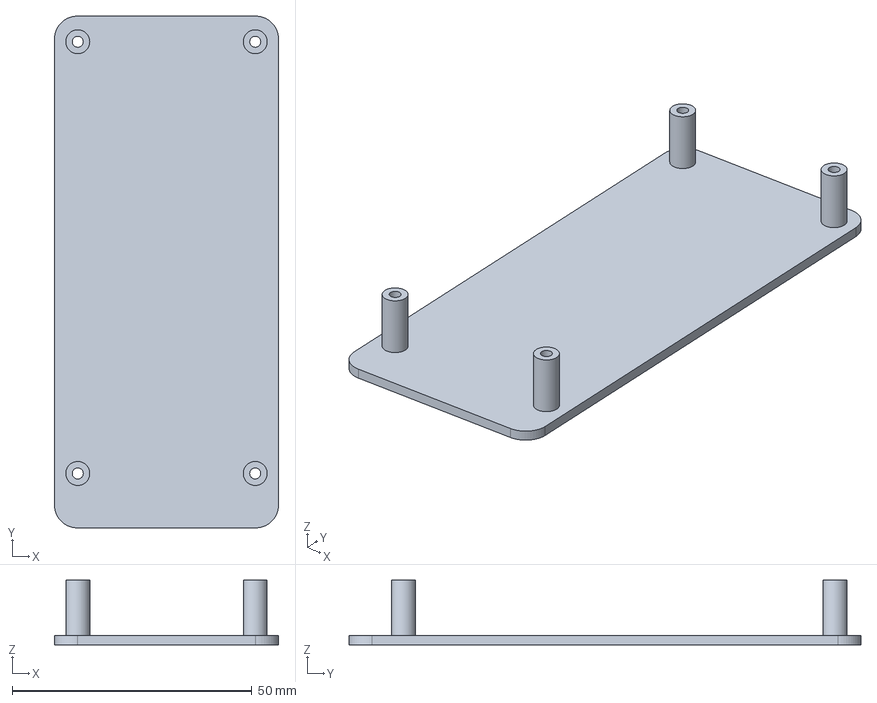
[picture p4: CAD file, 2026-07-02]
hardware/enclosure/output/back_lid.step
46.7 x 106.7 x 13.5 mm

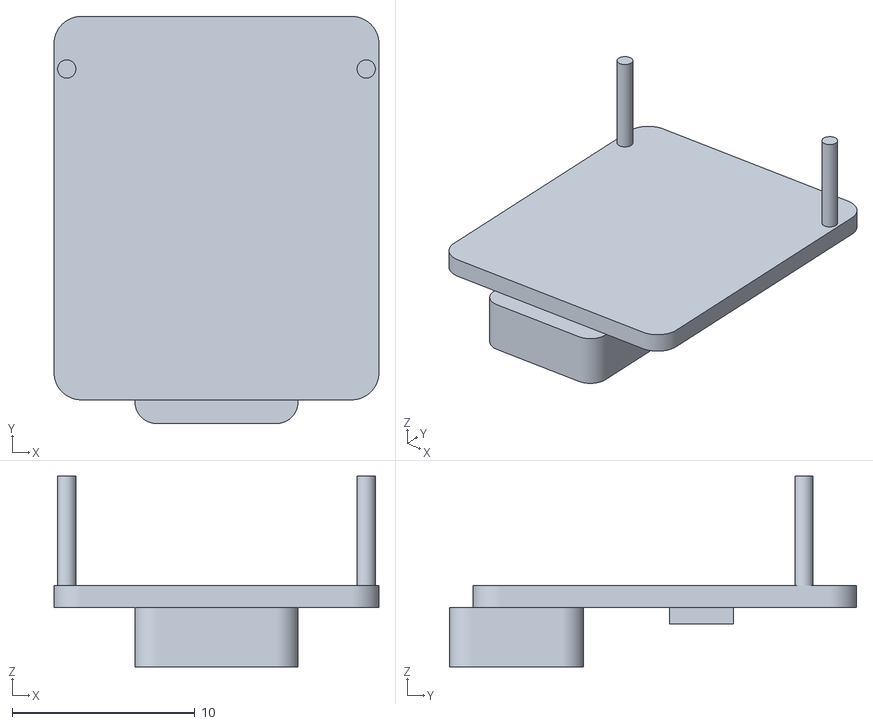
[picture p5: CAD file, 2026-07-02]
hardware/mockup/output/parts/xiao.stl
17.8 x 22.3 x 10.5

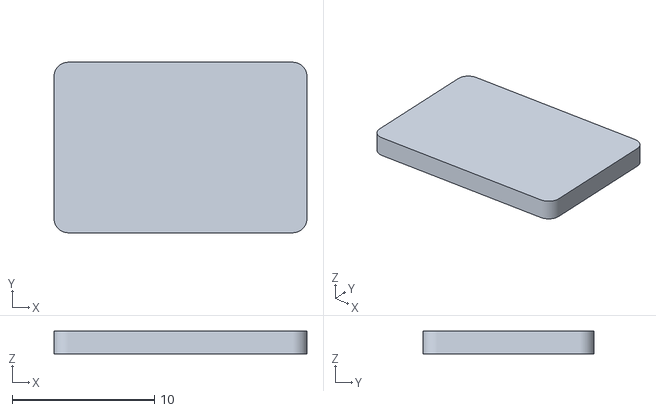
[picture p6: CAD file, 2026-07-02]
hardware/mockup/output/parts/mic.stl
17.8 x 12.0 x 1.60

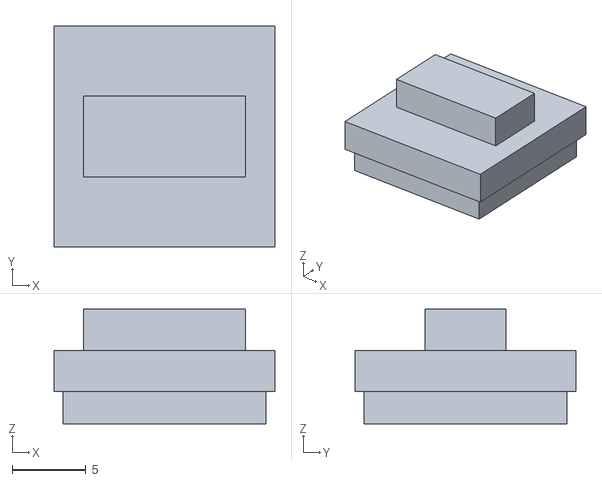
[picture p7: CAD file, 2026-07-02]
hardware/mockup/output/parts/switch_ptt.stl
15.0 x 15.0 x 7.80

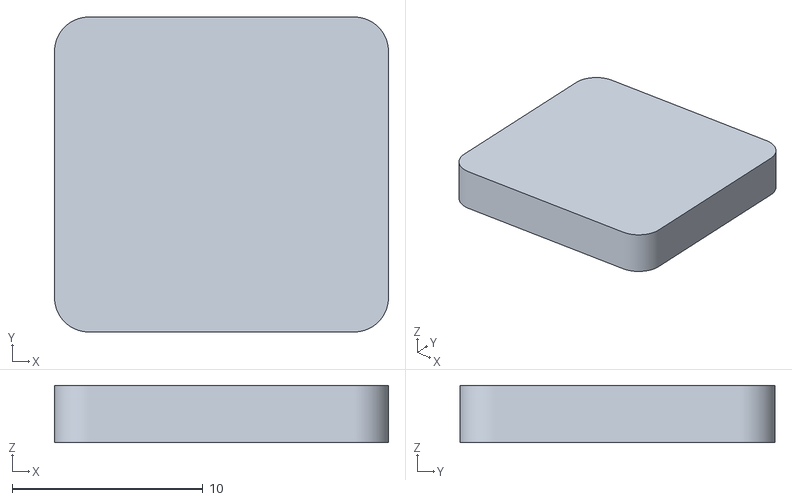
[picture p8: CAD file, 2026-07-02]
hardware/mockup/output/parts/cap_remember.stl
17.5 x 16.5 x 3.00

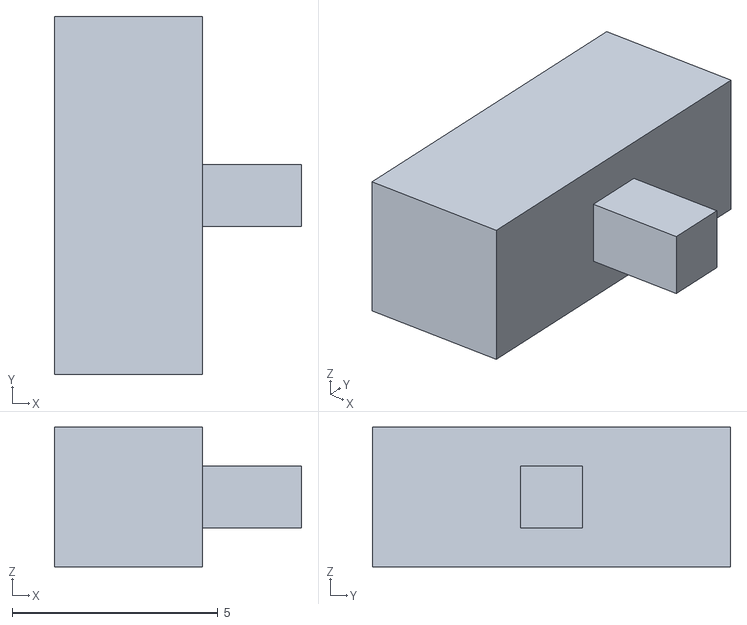
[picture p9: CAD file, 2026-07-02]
hardware/mockup/output/parts/slide.stl
6.00 x 8.70 x 3.40

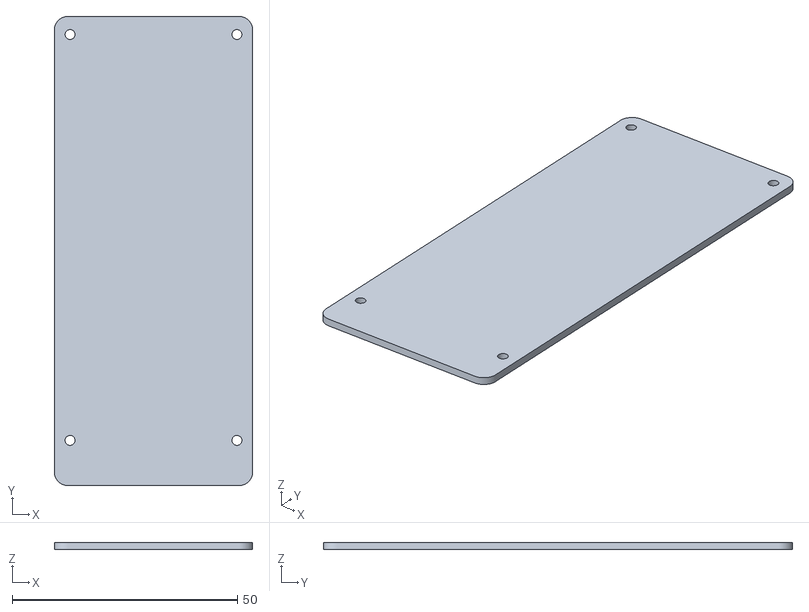
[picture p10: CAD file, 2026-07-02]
hardware/mockup/output/parts/pcb.stl
44.0 x 104.0 x 1.60

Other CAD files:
hardware/mockup/output/parts/back_lid.stl
hardware/mockup/output/parts/front_shell.stl
hardware/mockup/output/parts/switch_reject.stl
hardware/mockup/output/parts/cap_mode.stl
hardware/mockup/output/parts/switch_approve.stl
hardware/mockup/output/parts/cap_ptt.stl
hardware/mockup/output/parts/switch_mode.stl
hardware/mockup/output/parts/cap_approve.stl
hardware/enclosure/output/back_lid.stl
hardware/enclosure/output/front_shell.stl
hardware/mockup/output/parts/cap_reject.stl
hardware/mockup/output/parts/switch_remember.stl

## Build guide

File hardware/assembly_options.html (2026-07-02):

# Build options v2.1: 5 boards, DIY → turnkey

Claude Code Companion Peripheral · re-estimated 2026-07-02 for the all-THT/header BOM (pre-soldered XIAO, mic breakout module, addressable RGB LED). All figures are estimates, not quotes — JLCPCB/PCBWay block automated fetches, so prices come from ~14 triangulated search queries against catalog/forum data. A live quote is the only way to firm these up further.

What changed from the last pass: the old BOM's "zero solder" story rested on a bare LGA mic chip needing reflow — that's gone. Now the open question is different: the XIAO and mic modules (not simple components) may not be placeable by either vendor's standard pick-and-place at all, regardless of price. But that cuts both ways — those 20 through-hole joints are now the easiest part of the build, so full DIY no longer needs hot-air/reflow tooling either. The real lesson: get a real PCBWay quote for the two modules before assuming either "zero solder" or "vendor won't touch it."

## Estimated all-in cost — 5 boards' materials, shipped

Includes PCB fab, parts, vendor fees, keycaps, shipping. Scale $150–$500 — wider than last pass because of real price spread on the XIAO/mic breakout and genuine uncertainty on option D.

A · Full DIY$170–255

B · Vendor: fiddly SMD/THT only$225–330

C · Vendor: everything but 2 modules$245–355

D · Speculative full turnkey$260–470

E · Whole device (C + enclosure)$285–430

$150$250$350$450

materials + fees + shipping speculative range (D) — unconfirmed vendor capability

## A · Full DIY $170–255

5 bare PCBs + every part bought retail; you solder all ~17 components per board.

✓ no reflow/hot-air needed Effort

### You do

- 20 big, easy THT joints per board for the 2 modules (XIAO + mic breakout) — no fine work at all
- 5 Choc switches + fine-tip-iron work on the 1 SMD LED and 1 SMD latch switch
- ~1–2 h/board, ~5–10 h total for 5 — down a lot from the old bare-mic-chip build

### Where the money goes

- PCB fab ~$10–20/5 (board's 104mm length exceeds JLCPCB's $2 bracket)
- Parts/board: XIAO ~$9–24 · mic breakout ~$7–15 · 5 switches ~$3–4.50 · 5 caps ~$4–4.75 · latch switch ~$1–2 · LED+passives ~$1
- 3+ supplier shipments ~$20–30

No special tools needed anymore — a fine-tip iron handles everything, including the SMD LED (gull-wing pads, not the old reflow-only mic chip).

## B · Vendor solders the fiddly bits only $225–330

Vendor assembles the LED, latch switch, and passives (the small SMD/THT parts) via standard PCBA. You solder the 5 keyswitches and both modules yourself.

✓ beginner-level iron work Effort

### You do

- ~30 THT joints/board: 5 switches + 20 module pins — all big, easy, no fine work
- ~20–30 min/board

### Vendor does

- LED, latch switch, passives via standard SMD/THT line
- Fees: setup+stencil ~$35–70, part-line loading ~$5–10

Worth it mainly if hand-soldering the small SMD LED/latch switch feels intimidating — otherwise Option A gets you most of the way for less.

Recommended

## C · Vendor does everything except the 2 modules $245–355

The realistic "best vendor tier" ceiling: keyswitches, latch switch, LED, and passives all vendor-assembled. You solder only the XIAO and mic breakout — 20 big through-hole pins, no fine work whatsoever.

✓ easiest reliable tier Effort

- ~10–15 min/board: push 20 pins through, flip, solder
- Doesn't depend on either vendor agreeing to place an irregular header-mounted module — the one part of this build that's genuinely uncertain is skipped entirely
- Fees similar to B plus wave/hand-solder labor for the 5 keyswitches (~$3.50 + ~$0.015/joint)

This is the sensible default: it doesn't gamble on an unconfirmed vendor capability, and the 20 joints it leaves you are the easiest ones in the whole design.

Speculative — needs a real quote

## D · Full turnkey, zero solder $260–470

PCBWay's consigned/combo parts program explicitly supports customer-supplied parts — in principle you could ship them the XIAO + mic breakout for placement, achieving genuine zero solder. JLCPCB's standard flow likely declines this (no customer-supplied parts outside their library).

? feasibility unconfirmed Effort

- Real risk: an EEVblog thread titled "JLCPCB assembly — massive Manual Assembly fee" is a live warning that irregular-part placement fees can blow past expectations — a header-pin module standing 8–10mm off the board is exactly this class of part
- Only get quoted, don't order, until PCBWay's sales team confirms they'll actually take the job and at what fee
- If the quote comes back reasonable, this is genuinely zero-solder; if not, fall back to C — the switches/passives/LED work is identical either way

## E · Whole device, one vendor $285–430

Option C (the reliable tier) plus 5 sets of enclosure shells from JLC3DP or PCBWay's print service, in one combined order. STL/STEP files already in hardware/enclosure/output/.

✓ one order, easy self-assembly Effort

- Shell pairs est. $5–12 each in gray resin/PA12
- Your entire build: solder 2 modules (10–15 min) + 4 screws + 5 keycaps per device
- Swap in D's modules-included cost if that quote comes back reasonable

Sensible after the layout sign-off (issue #12) and one fit-check print — the enclosure grew to 22.6mm thick this revision, worth confirming in hand before ordering 5 sets.

## Side-by-side

Option | Est. cost* | Your labor | Solder risk | Lead time
A DIY | $170–255 | 5–10 h | Low (no reflow anywhere) | ~2 wks, 3+ shipments
B Fiddly bits done | $225–330 | ~2–2.5 h easy THT | Low | ~2–3 wks, 2 shipments
C All but 2 modules | $245–355 | ~1 h, big pins only | Lowest | ~2–3 wks, 2 shipments
D Speculative turnkey | $260–470 | caps + screws | None if confirmed | unknown — quote first
E Device kit | $285–430 | 2 modules + caps + screws | Low | ~2–3.5 wks, 1–2 shipments

*Totals for 5 boards' materials incl. shipping and keycaps. Wider ranges than the previous pass reflect real price spread found this round (XIAO pre-soldered $9–24 depending on source/region; mic breakout $7–15) plus D's genuine feasibility uncertainty.

## Caveats & the one real next step

- Routing still doesn't change this math — assembly cost keys off board size, layer count, and part count, all fixed. The board is placed + netlisted, not routed (issue #13).
- New this pass: the C&K PCM12SMTR latch switch is listed Obsolete by one distributor — still orderable elsewhere at this writing, but pick a confirmed-active replacement before finalizing (issue #16). Not reflected as a cost swing above since a replacement part's price is unknown.
- XIAO pre-soldered pricing varies widely by source/region (£19 UK retail vs. likely cheaper direct-from-Seeed US pricing) — get one real quote rather than trusting either end of that range.
- Option D's range is wide on purpose — module-placement fees are the one thing search snippets categorically cannot verify. Don't treat either end of $260–470 as a real number.

Bottom line: pick C as the default — it doesn't gamble on unconfirmed vendor capability, and what it leaves you to solder (2 modules, 20 big pins) is genuinely the easiest part of the build. Get a real PCBWay quote for D before ruling it out; upgrade to E once the enclosure fit-check print is done.

agent-ptt-mic · hardware/assembly_options.html · v2.1 estimates prepared 2026-07-02

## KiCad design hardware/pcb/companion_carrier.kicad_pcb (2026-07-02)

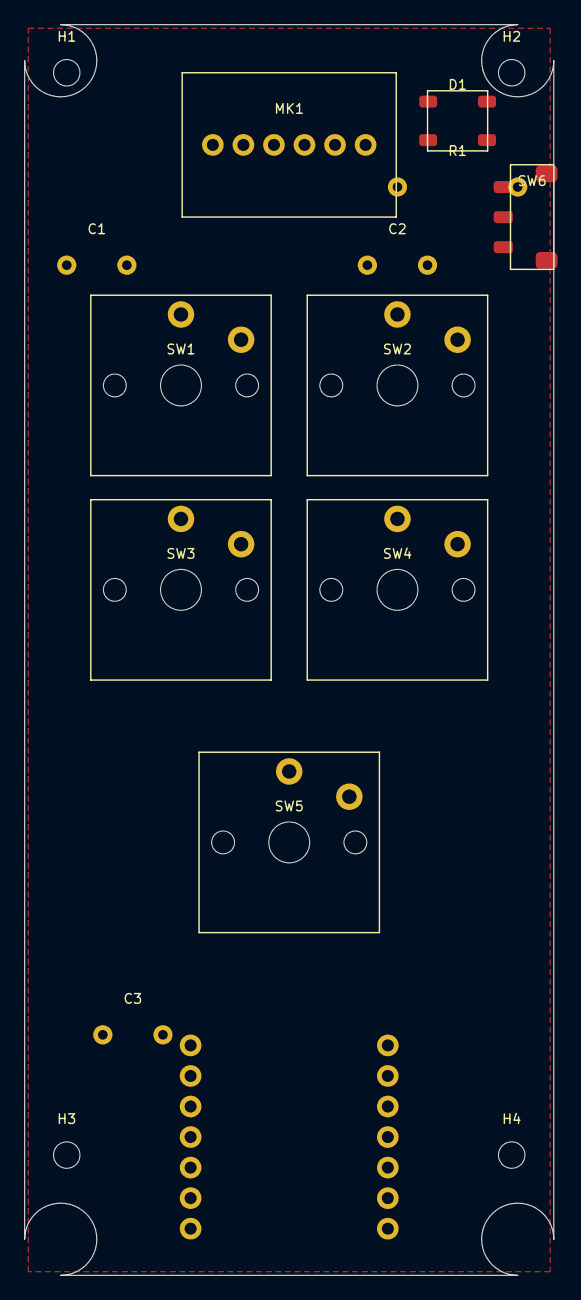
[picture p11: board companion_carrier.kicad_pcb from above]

Board: 2 copper layers, 44.0 x 104.0 mm, 17 parts (1 on the bottom side), 13 nets, no tracks yet.

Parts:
C1, C2, C3: THT_passive
D1: WS2812B_5050
H1, H2, H3, H4: MountingHole_M2
MK1: MicBreakout_SPH0645-style
R1: THT_passive
SW1, SW2, SW3, SW4, SW5: Kailh_Choc_V1
SW6: CK_PCM12SMTR
U1: XIAO-RP2040_preSoldered_header

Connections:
3V3: C1.1, C2.1, C3.1, D1.1, MK1.P1, U1.L5
GND: C1.2, C2.2, C3.2, D1.3, MK1.P2, MK1.P6, SW1.2, SW2.2, SW3.2, SW4.2, SW5.2, SW6.2, U1.L6
I2S_BCLK: MK1.P3, U1.R3
I2S_LRCLK: MK1.P5, U1.R2
I2S_SD: MK1.P4, U1.R4
KEY_APPROVE: SW1.1, U1.R5
KEY_MODE: SW4.1, U1.L2
KEY_REJECT: SW3.1, U1.L1
KEY_REMEMBER: SW2.1, U1.R1
LATCH: SW6.1, U1.R6
LED_DATA: R1.1, U1.L4
LED_DIN: D1.4, R1.2
PTT: SW5.1, U1.R7

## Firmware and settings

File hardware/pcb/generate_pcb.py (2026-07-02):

"""Generate the carrier-board KiCad PCB (`companion_carrier.kicad_pcb`).

Produces a netlisted, fully-placed 2-layer board: XIAO RP2040 module
(pre-soldered/header variant -- through-hole pins, mounted on the BACK),
5x Kailh Choc V1 keyswitches, PCM12SMTR side-actuated latch slide, an I2S
mic BREAKOUT MODULE (header-mounted, front side -- not a bare SMD chip),
an addressable RGB status LED (v2.1, see design_params.py for why),
THT decoupling passives,
mounting holes, board outline, and GND zones on both copper layers.

2026-07-02 revision: every active part on this board is now a
through-hole / header-mount component, hand-solderable with a plain iron
-- no reflow or hot-air needed anywhere (see hardware/BOM.md and
docs/PHYSICAL_DESIGN_SPEC.md for why: the XIAO Geoff ordered is the
pre-soldered/header SKU, and the mic and LED were swapped off bare-SMD/
addressable parts to match).

Deliberately NOT routed: signal traces are left to an interactive KiCad
session where DRC runs live (see README.md in this directory). Every net
is attached to its pads, so the ratsnest is complete when opened.

Run from the repo root:  python3 hardware/pcb/generate_pcb.py
"""

import math
import os
import sys

sys.path.insert(0, os.path.join(os.path.dirname(__file__), ".."))
import design_params as P  # noqa: E402

from kiutils.board import Board  # noqa: E402
from kiutils.footprint import Footprint, Pad, DrillDefinition, Attributes  # noqa: E402
from kiutils.items.common import Net, Position, Effects, Font  # noqa: E402
from kiutils.items.gritems import GrLine, GrArc  # noqa: E402
from kiutils.items.fpitems import FpText, FpLine, FpCircle  # noqa: E402
from kiutils.items.zones import Zone, FillSettings, Hatch, ZonePolygon  # noqa: E402
from kiutils.items.brditems import LayerToken  # noqa: E402

# Board-space -> sheet-space offset (keeps the board away from the sheet origin)
OX, OY = 60.0, 30.0


def pos(x, y, angle=None):
    """Board space (x from centreline, y from top edge) -> KiCad sheet mm."""
    return Position(X=round(OX + x, 3), Y=round(OY + y, 3), angle=angle)


# --------------------------------------------------------------------------
# Nets
# --------------------------------------------------------------------------
NET_NAMES = [
    "", "GND", "3V3", "5V",
    "PTT", "LATCH", "KEY_APPROVE", "KEY_REMEMBER", "KEY_REJECT", "KEY_MODE",
    "I2S_SD", "I2S_BCLK", "I2S_LRCLK", "LED_DATA", "LED_DIN", "SPARE_D9",
]
NETS = {name: Net(number=i, name=name) for i, name in enumerate(NET_NAMES)}


def net(name):
    return Net(number=NETS[name].number, name=name)


# --------------------------------------------------------------------------
# Pad helpers
# --------------------------------------------------------------------------
def smd_pad(number, x, y, w, h, netname=None, layer="F.Cu"):
    mask = "F.Mask" if layer == "F.Cu" else "B.Mask"
    paste = "F.Paste" if layer == "F.Cu" else "B.Paste"
    return Pad(
        number=str(number), type="smd", shape="roundrect",
        position=Position(X=round(x, 3), Y=round(y, 3)),
        size=Position(X=w, Y=h), layers=[layer, mask, paste],
        roundrectRatio=0.25,
        net=net(netname) if netname else None,
    )


def tht_pad(number, x, y, pad_d, drill_d, netname=None):
    return Pad(
        number=str(number), type="thru_hole", shape="circle",
        position=Position(X=round(x, 3), Y=round(y, 3)),
        size=Position(X=pad_d, Y=pad_d),
        drill=DrillDefinition(diameter=drill_d),
        layers=["*.Cu", "*.Mask"],
        net=net(netname) if netname else None,
    )


def npth(x, y, drill_d):
    return Pad(
        number="", type="np_thru_hole", shape="circle",
        position=Position(X=round(x, 3), Y=round(y, 3)),
        size=Position(X=drill_d, Y=drill_d),
        drill=DrillDefinition(diameter=drill_d),
        layers=["*.Cu", "*.Mask"],
    )


def ref_text(ref, y=-3.0, layer="F.SilkS", hide=False):
    return FpText(
        type="reference", text=ref, position=Position(X=0, Y=y),
        layer=layer, hide=hide,
        effects=Effects(font=Font(height=0.8, width=0.8, thickness=0.12)),
    )


def fp(name, ref, at, pads, extra_items=None, layer="F.Cu", smd=True):
    f = Footprint(
        libraryNickname="carrier", entryName=name,
        version="20240108", generator="generate_pcb.py",
        layer=layer, position=at,
        attributes=Attributes(type="smd" if smd else "through_hole"),
        pads=pads,
        graphicItems=[ref_text(ref, layer="F.SilkS" if layer == "F.Cu" else "B.SilkS")]
        + (extra_items or []),
    )
    return f


def header_row(prefix, cx, cy0, count, pitch, nets, pad_d=1.8, drill_d=1.0,
               vertical=True):
    """A single row of THT header pins -- used for both the XIAO module's
    presoldered pins (pushed through the carrier and soldered) and the mic
    breakout's header."""
    pads = []
    for i in range(count):
        y = cy0 + i * pitch if vertical else cy0
        x = cx if vertical else cx + i * pitch
        pads.append(tht_pad(f"{prefix}{i+1}", x, y, pad_d, drill_d, nets[i]))
    return pads


def outline_lines(w, h, layer="F.SilkS"):
    x, y = w / 2, h / 2
    pts = [(-x, -y), (x, -y), (x, y), (-x, y), (-x, -y)]
    return [
        FpLine(start=Position(X=pts[i][0], Y=pts[i][1]),
               end=Position(X=pts[i + 1][0], Y=pts[i + 1][1]),
               layer=layer, width=0.12)
        for i in range(4)
    ]


# --------------------------------------------------------------------------
# Footprints
# --------------------------------------------------------------------------
def xiao_rp2040(ref, cx, cy):
    """XIAO module -- PRE-SOLDERED/header SKU, mounted on the carrier's
    BACK. Its own presoldered header pins pass through 14 plated holes and
    solder flush on the carrier's front copper; no separate header/socket
    part needed (see design_params.py XIAO_MODULE_STANDOFF). Component
    side (RP2040, USB-C) faces away from the carrier, into the back shell
    cavity -- USB-C points to +Y (board bottom edge).

    Pin map viewed from the BACK (component side facing away): the module
    is rotated 180 deg from Seeed's usual USB-up/top-view drawing, so the
    columns swap/flip same as the prior flush-mount revision.
    VERIFY pad geometry against Seeed's official footprint before fab.
    """
    pitch, col_x = P.XIAO_PAD_PITCH, P.XIAO_HDR_ROW_SPACING / 2
    left = ["KEY_REJECT", "KEY_MODE", "SPARE_D9", "LED_DATA", "3V3", "GND", "5V"]
    right = ["KEY_REMEMBER", "I2S_LRCLK", "I2S_BCLK", "I2S_SD",
             "KEY_APPROVE", "LATCH", "PTT"]
    y0 = -pitch * 3
    pads = (header_row("L", -col_x, y0, 7, pitch, left)
            + header_row("R", col_x, y0, 7, pitch, right))
    body = outline_lines(P.XIAO_W, P.XIAO_L, layer="B.SilkS")
    usb = outline_lines(P.XIAO_USB_W, 7.35, layer="B.SilkS")
    for line in usb:
        line.start.Y += P.XIAO_L / 2 - 7.35 / 2 + P.XIAO_USB_OVERHANG
        line.end.Y += P.XIAO_L / 2 - 7.35 / 2 + P.XIAO_USB_OVERHANG
    return fp("XIAO-RP2040_preSoldered_header", ref, pos(cx, cy), pads,
              layer="B.Cu", smd=False,
              extra_items=body + usb + [
                  FpText(type="user", text="USB-C v (hangs off back)",
                         layer="B.SilkS",
                         position=Position(X=0, Y=P.XIAO_L / 2 - 2),
                         effects=Effects(font=Font(height=0.7, width=0.7,
                                                   thickness=0.11)))])


def choc_v1(ref, cx, cy, netname):
    """Kailh Choc V1 (PG1350). Contacts: pin1 -> GPIO net, pin2 -> GND."""
    pads = [
        npth(0, 0, P.CHOC_STEM_HOLE),
        npth(-P.CHOC_POST_X, 0, P.CHOC_POST_HOLE),
        npth(P.CHOC_POST_X, 0, P.CHOC_POST_HOLE),
        tht_pad(1, P.CHOC_PIN1[0], P.CHOC_PIN1[1], 2.2, P.CHOC_PIN_HOLE, netname),
        tht_pad(2, P.CHOC_PIN2[0], P.CHOC_PIN2[1], 2.2, P.CHOC_PIN_HOLE, "GND"),
    ]
    body = outline_lines(P.CHOC_BODY, P.CHOC_BODY)
    cap = outline_lines(P.CAP_W, P.CAP_D, layer="F.Fab")
    return fp("Kailh_Choc_V1", ref, pos(cx, cy), pads,
              extra_items=body + cap, smd=False)


def slide_pcm12(ref, cx, cy):
    """C&K PCM12SMTR, right-angle SMT; actuator toward +X past board edge.

    Terminals face -X (into the board). VERIFY land pattern vs datasheet.
    """
    pads = [
        smd_pad(1, -2.4, -2.5, 1.6, 1.0, "LATCH"),
        smd_pad(2, -2.4, 0.0, 1.6, 1.0, "GND"),
        smd_pad(3, -2.4, 2.5, 1.6, 1.0, None),
        smd_pad("MP1", 1.2, -3.6, 1.8, 1.4, None),
        smd_pad("MP2", 1.2, 3.6, 1.8, 1.4, None),
    ]
    body = outline_lines(P.SLIDE_BODY_W, P.SLIDE_BODY_L)
    return fp("CK_PCM12SMTR", ref, pos(cx, cy), pads, extra_items=body)


def mic_breakout(ref, cx, cy):
    """I2S mic breakout MODULE (e.g. Adafruit SPH0645, PID 3421) -- a
    6-pin THT header, front side, standing off the carrier per
    MIC_BRK_STANDOFF. Same signal order as the breadboard-track wiring in
    docs/SPEC.md §8. Pin spacing/positions approximate -- VERIFY against
    the physical breakout before finalizing the enclosure window."""
    nets = ["3V3", "GND", "I2S_BCLK", "I2S_SD", "I2S_LRCLK", "GND"]  # SEL->GND
    n = P.MIC_BRK_PINS
    x0 = -(n - 1) * P.MIC_BRK_PIN_PITCH / 2
    pads = header_row("P", x0, 0.0, n, P.MIC_BRK_PIN_PITCH, nets,
                      vertical=False)
    body = outline_lines(P.MIC_BRK_L, P.MIC_BRK_W)
    return fp("MicBreakout_SPH0645-style", ref, pos(cx, cy), pads,
              extra_items=body, smd=False)


def led_addressable(ref, cx, cy):
    """WS2812B/SK6812-style 5050 addressable RGB LED -- v2.1: reintroduced
    despite not being strictly required, because it's the only way to get
    full RGB from the single GPIO the pin budget actually has spare (see
    design_params.py LED section for the full reasoning). Data in via R1
    from LED_DATA/GPIO3; DOUT unused (not chained to a second LED)."""
    pads = [
        smd_pad(1, -2.45, -1.6, 1.5, 1.0, "3V3"),
        smd_pad(2, -2.45, 1.6, 1.5, 1.0, None),        # DOUT, unused
        smd_pad(3, 2.45, 1.6, 1.5, 1.0, "GND"),
        smd_pad(4, 2.45, -1.6, 1.5, 1.0, "LED_DIN"),
    ]
    body = outline_lines(P.LED_SIZE, P.LED_SIZE)
    return fp("WS2812B_5050", ref, pos(cx, cy), pads, extra_items=body)


def passive_0603(ref, cx, cy, net1, net2, angle=None):
    pads = [
        smd_pad(1, -0.775, 0, 0.9, 1.0, net1),
        smd_pad(2, 0.775, 0, 0.9, 1.0, net2),
    ]
    return fp(f"R_C_0603", ref, pos(cx, cy, angle), pads,
              extra_items=outline_lines(1.6, 0.8, layer="F.Fab"))


def passive_tht(ref, cx, cy, net1, net2, spacing, pad_d=1.6, drill_d=0.8):
    """Generic THT passive (radial ceramic cap or axial resistor, formed
    to a vertical/radial lead spacing) -- hand-solderable, no fine-pitch
    tweezer work. Used for the decoupling caps and the LED series
    resistor so the whole board stays iron-only."""
    half = spacing / 2
    pads = [
        tht_pad(1, -half, 0, pad_d, drill_d, net1),
        tht_pad(2, half, 0, pad_d, drill_d, net2),
    ]
    return fp("THT_passive", ref, pos(cx, cy), pads,
              extra_items=outline_lines(spacing + 1.0, 2.0, layer="F.Fab"),
              smd=False)


def mount_hole(ref, cx, cy):
    return fp("MountingHole_M2", ref, pos(cx, cy), [npth(0, 0, P.PCB_HOLE_D)],
              smd=False)


# --------------------------------------------------------------------------
# Board outline (rounded rectangle on Edge.Cuts)
# --------------------------------------------------------------------------
def edge_cuts():
    w, h, r = P.PCB_W, P.PCB_L, P.PCB_CORNER_R
    x0, x1, y0, y1 = -w / 2, w / 2, 0.0, h
    items = []

    def gl(xa, ya, xb, yb):
        items.append(GrLine(start=pos(xa, ya), end=pos(xb, yb),
                            layer="Edge.Cuts", width=0.1))

    def garc(cx, cy, start, end):
        # KiCad arc: start point, mid point, end point (CCW start->end here
        # computed explicitly per corner).
        items.append(GrArc(start=start, mid=cy_mid(cx, cy, start, end),
                           end=end, layer="Edge.Cuts", width=0.1))

    def cy_mid(cx, cy, s, e):
        a0 = math.atan2(s.Y - (OY + cy), s.X - (OX + cx))
        a1 = math.atan2(e.Y - (OY + cy), e.X - (OX + cx))
        while a1 < a0:
            a1 += 2 * math.pi
        am = (a0 + a1) / 2
        return Position(X=round(OX + cx + r * math.cos(am), 4),
                        Y=round(OY + cy + r * math.sin(am), 4))

    gl(x0 + r, y0, x1 - r, y0)                       # top
    garc(x1 - r, y0 + r, pos(x1, y0 + r), pos(x1 - r, y0))
    gl(x1, y0 + r, x1, y1 - r)                       # right
    garc(x1 - r, y1 - r, pos(x1 - r, y1), pos(x1, y1 - r))
    gl(x1 - r, y1, x0 + r, y1)                       # bottom
    garc(x0 + r, y1 - r, pos(x0, y1 - r), pos(x0 + r, y1))
    gl(x0, y1 - r, x0, y0 + r)                       # left
    garc(x0 + r, y0 + r, pos(x0 + r, y0), pos(x0, y0 + r))
    return items


def gnd_zone(layer):
    m = 0.3
    w, h = P.PCB_W, P.PCB_L
    corners = [(-w / 2 + m, m), (w / 2 - m, m), (w / 2 - m, h - m),
               (-w / 2 + m, h - m)]
    poly = ZonePolygon(coordinates=[pos(x, y) for x, y in corners])
    return Zone(
        net=NETS["GND"].number, netName="GND", layers=[layer],
        name=f"GND_{layer}", hatch=Hatch(style="edge", pitch=0.5),
        clearance=0.4, minThickness=0.25,
        fillSettings=FillSettings(thermalGap=0.4, thermalBridgeWidth=0.4),
        polygons=[poly],
    )


# --------------------------------------------------------------------------
# Assemble board
# --------------------------------------------------------------------------
def build():
    board = Board.create_new()
    board.generator = "agent-ptt-mic/hardware/pcb/generate_pcb.py"
    board.nets = [NETS[n] for n in NET_NAMES]

    fps = []
    # Keyswitches (nets per docs/SPEC.md §8 + hardware/BOM.md)
    key_nets = {"approve": "KEY_APPROVE", "remember": "KEY_REMEMBER",
                "reject": "KEY_REJECT", "mode": "KEY_MODE", "ptt": "PTT"}
    sw_ref = {"approve": "SW1", "remember": "SW2", "reject": "SW3",
              "mode": "SW4", "ptt": "SW5"}
    for name, (x, y) in P.KEY_POS.items():
        fps.append(choc_v1(sw_ref[name], x, y, key_nets[name]))

    fps.append(slide_pcm12("SW6", P.PCB_W / 2 - P.SLIDE_BODY_W / 2,
                           P.SLIDE_POS_Y))
    fps.append(mic_breakout("MK1", *P.MIC_POS))
    fps.append(led_addressable("D1", *P.LED_POS))
    fps.append(xiao_rp2040("U1", 0.0, P.XIAO_POS_Y))

    # Passives: THT (radial/axial leads) except the LED itself, which is
    # the one deliberately-reintroduced SMD part (see design_params.py).
    # Mic decoupling near mic, LED data-line resistor near LED, bulk cap
    # near the XIAO's 3V3 pins.
    fps.append(passive_tht("C1", -16.0, 20.0, "3V3", "GND", spacing=5.0))
    fps.append(passive_tht("C2", 9.0, 20.0, "3V3", "GND", spacing=5.0))
    fps.append(passive_tht("R1", 14.0, 13.5, "LED_DATA", "LED_DIN",
                           spacing=P.RES_THT_LEAD_SPACING))
    fps.append(passive_tht("C3", -13.0, 84.0, "3V3", "GND",
                           spacing=5.0))  # clear of U1

    for i, (x, y) in enumerate(P.PCB_HOLES, start=1):
        fps.append(mount_hole(f"H{i}", x, y))

    board.footprints = fps
    board.graphicItems = edge_cuts()
    board.zones = [gnd_zone("F.Cu"), gnd_zone("B.Cu")]
    return board


if __name__ == "__main__":
    out = os.path.join(os.path.dirname(__file__), "companion_carrier.kicad_pcb")
    build().to_file(out)
    # Round-trip check: re-parse what we wrote.
    reparsed = Board.from_file(out)
    print(f"OK: {out}")
    print(f"  {len(reparsed.footprints)} footprints, "
          f"{len(reparsed.nets)} nets, {len(reparsed.zones)} zones, "
          f"{len(reparsed.graphicItems)} edge items")

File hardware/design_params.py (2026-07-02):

"""Single source of dimensional truth for the carrier PCB, enclosure, and
3D mockup. Every consumer (PCB generator, enclosure CAD, mockup assembly)
imports from here — never re-declare a dimension locally.

All dimensions in millimetres. Origin convention for board-space coordinates:
X=0 at board centreline (+X right when looking at the front face),
Y=0 at board top edge (+Y downward toward the USB-C end).

Dimension sources are noted per block. Anything marked VERIFY must be
checked against the current datasheet/physical part before ordering
fabrication — these values are correct per the datasheets as known at
design time, but the project convention (docs/SPEC.md §0) is to re-verify
time-sensitive facts.

Mounting revision (2026-07-02): the XIAO RP2040 Geoff ordered is the
PRE-SOLDERED variant (docs/SPEC.md §4) -- it arrives with 0.1" pin headers
already on it, not bare castellated edges meant for reflow onto a carrier.
Likewise the mic is a breakout MODULE (pin-header, like the original
breadboard-track SPH0645 breakout), not a bare SMD chip, and the status
LED is a plain THT LED, not an addressable SMD WS2812B. Net effect: the
whole carrier is now hand-iron-solderable, no reflow/hot-air anywhere --
at the cost of a notably thicker enclosure, since a header-mounted module
needs real standoff clearance instead of sitting flush.
"""

# --------------------------------------------------------------------------
# Seeed Studio XIAO RP2040 module -- PRE-SOLDERED variant (pin headers)
# Source: Seeed wiki pinout (X-Y pin spacing is a fixed module dimension,
# unchanged by header-vs-castellated). Header standoff/pin-length figures
# are typical-for-class estimates -- VERIFY against the physical board
# before finalizing enclosure thickness.
# --------------------------------------------------------------------------
XIAO_L = 21.0          # module PCB length (along USB axis)
XIAO_W = 17.8          # module PCB width
XIAO_PCB_T = 1.2       # module PCB thickness
XIAO_PAD_PITCH = 2.54  # header pin pitch, 7 per long side
XIAO_PADS_PER_SIDE = 7
XIAO_USB_W = 8.94      # USB-C connector width
XIAO_USB_H = 3.26      # USB-C connector height (above module top face)
XIAO_USB_OVERHANG = 1.3   # connector protrusion past module PCB edge

# Mounting: module sits on the carrier's BACK, pin-side facing the carrier.
# Its own presoldered header pins pass through 14 plated holes in the
# carrier and solder flush on the carrier's FRONT copper (a clear area near
# the bottom edge, away from the switch cluster) -- no separate header/
# socket part needed, and it's permanent rather than a swappable socket
# (simplest + thinnest of the two mounting options; a female-header socket
# would add another ~8.5mm of standoff for zero benefit at this quantity).
XIAO_HDR_ROW_SPACING = 16.4  # column-to-column (was col_x*2 in prior rev)
XIAO_MODULE_STANDOFF = 6.0   # VERIFY: gap from carrier back face to module
                             # PCB underside, bridged by the module's own
                             # presoldered pin legs
XIAO_TOTAL_DEPTH = (XIAO_MODULE_STANDOFF + XIAO_PCB_T + XIAO_USB_H)  # 10.46
                             # carrier back face -> outward tip of USB-C
                             # (component side, incl. USB-C, faces AWAY
                             # from the carrier, deeper into the back shell)

# --------------------------------------------------------------------------
# Kailh Choc V1 (PG1350) low-profile mechanical keyswitch
# Source: Kailh PG1350 datasheet drawing; footprint cross-checked against
# the common community footprint (ai03 / keebio style).
# --------------------------------------------------------------------------
CHOC_BODY = 15.0          # top flange, square
CHOC_BODY_UNDER = 13.8    # lower housing, square (also plate-cutout size)
CHOC_H_ABOVE_PCB = 5.0    # housing top above PCB (excl. stem)
CHOC_STEM_H = 3.0         # stem above housing at rest
CHOC_PIN_DEPTH = 2.65     # pins/posts below PCB bottom
CHOC_STEM_HOLE = 3.4      # centre locating post hole dia
CHOC_POST_HOLE = 1.9      # side locating post hole dia
CHOC_POST_X = 5.5         # side posts at (±5.5, 0)
CHOC_PIN1 = (0.0, -5.9)   # switch contact 1 (x, y) rel. to switch centre
CHOC_PIN2 = (5.0, -3.8)   # switch contact 2  — VERIFY handed variant
CHOC_PIN_HOLE = 1.2       # contact pin hole dia (plated)

# MBK / Choc-profile keycap
CAP_W = 17.5              # 1u Choc cap, X
CAP_D = 16.5              # 1u Choc cap, Y
CAP_H = 3.0               # cap slab thickness
CAP_TOP_ABOVE_PCB = 10.8  # cap top surface above PCB (switch + cap stack)

KEY_PITCH_X = 18.0        # Choc-standard key spacing
KEY_PITCH_Y = 17.0
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

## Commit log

2026-07-01 Add project spec and initial repo scaffolding
    Saves the full handoff spec for the Claude Code Companion Peripheral
    (XIAO RP2040 composite HID+UAC2 device) and sets up baseline project
    structure: README, live status tracker, agent orientation doc, and
    placeholder firmware/hardware directories for the milestone plan.
    Claude-Session: https://claude.ai/code/session_016ESUrPmzfisJUeUMDe4Dop
2026-07-01 Link open questions and milestone tracker to their GitHub issues
    Cross-references docs/STATUS.md with the issues filed for each open
    question (OQ1-OQ7), the board-arrival checklist, the button-count
    reconciliation, and the M1-M7 milestone tracker, so they stay
    discoverable from the status doc.
    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
2026-07-01 Add PCB / industrial-design track requirements and handoff doc
    Records Geoff's explicit request to start component selection, physical
    layout, custom PCB breakout design, enclosure design, and a 3D mockup
    ahead of the Milestone 7 gate, as a concurrent track alongside the
    breadboard plan. Captures the physical/aesthetic decisions gathered
    this session (handheld form factor, mechanical keyswitches, FDM
    printing, minimalist surfaces for later UV-printed labels) plus the
    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
2026-07-02 Execute PCB/enclosure/mockup design pass per handoff doc
    Implements the full first design pass for the industrial-design track:
    - hardware/design_params.py: shared dimensional source of truth that the
    PCB generator, enclosure CAD, and mockup all import from
    - hardware/BOM.md: locked part picks (Kailh Choc V1 + MBK caps, C&K
    PCM12SMTR latch slide, bare SPH0645LM4H-B mic, WS2812B status LED on
    spare D10) and the full carrier netlist
    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
    [back_lid.step, back_lid.stl, cap_approve.stl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]
2026-07-02 Add mic/LED close-up renders and JLCPCB/PCBWay sourcing research
    render_mic_detail.py produces zoomed views proving the mic (back side,
    MK1) and status LED (front side, D1) are placed correctly -- they're
    just tiny relative to the 104mm board, easy to miss in the full-board
    renders.
    ASSEMBLY_SOURCING.md records the zero-solder assembly research: every
    BOM part, including the XIAO RP2040 module itself, appears to already
    have a JLCPCB assembly-library listing, which would let a single
    JLCPCB(+JLC3DP) order build the whole device with no customer
    soldering. Flagged for live-quote verification since both vendor sites
    blocked direct fetches and this is triangulated from search snippets.
    Co-Aut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
2026-07-02 Add assembly-options decision artifact (DIY -> zero-solder)
    Mobile-friendly HTML comparing five build paths for a 5-board run:
    full DIY (~\$115-145 + hot-air requirement), vendor-SMD/self-THT,
    everything-but-XIAO, full turnkey (~\$175-225, zero solder), and a
    whole-device kit with JLC3DP shells in one checkout (~\$210-280).
    Key finding: turnkey costs roughly the same as soldering the switches
    yourself, since retail switch kits + extra shipping match JLCPCB's THT
    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
2026-07-02 Switch carrier board to all-THT/header mounting (v2)
    Geoff pointed out the XIAO already carries all the MCU/USB/flash
    complexity, so this board should be "just a breakout for switches and
    a mic module" -- and confirmed the ordered XIAO is the pre-soldered/
    header SKU, which mounts via standoff pins rather than flush reflow.
    Combined with "keep the LED but make it simple THT," this became a
    full mounting revision:
    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
    [back_lid.step, back_lid.stl, companion_carrier.kicad_pcb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]
2026-07-02 v2.1: revert status LED to addressable RGB (pin budget forces it)
    Geoff asked for a true RGB status LED, noting it doesn't need to be
    addressable. Implementing it surfaced a real constraint: a discrete
    3-channel RGB LED needs 3 independent GPIOs, and the locked pin map
    (docs/SPEC.md §8) leaves only 2 spares after the 9 assigned signals --
    one short, with no multiplexing trick around it (charlieplexing only
    saves pins when LED count exceeds pin count, not for a single 3-channel
    part). Asked Geoff to choose between three resolutions; he picked
    reverting to an addressable LED, since it needs only the one GPIO the
    budget actually has spare.
    D1 is WS2812B/SK6812-style again -- the one deliberat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
    [companion_carrier.kicad_pcb, led.stl, mockup_assembly.step]
2026-07-02 Re-run assembly cost/sourcing research against the v2.1 BOM
    Redid the JLCPCB/PCBWay research (both sites still block WebFetch, so
    this is ~14 triangulated WebSearch queries including forum/community
    sources) now that the BOM has two real modules (XIAO, mic breakout)
    instead of simple components. Key findings:
    - JLCPCB's standard assembly flow generally doesn't accept
    customer-supplied parts outside their own library; PCBWay's
    Kitted/Consigned/Combo order types explicitly do -- this flips last
    round's JLCPCB lean, since neither module is a typical library part
    anymore
    - Real risk found: C&K PCM12SMTR (the latch switch) is listed Obsolete
    by one distributor -- flagged in BOM.md and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
2026-07-02 Hand off to local research agent: document SW6 gap, leave BOM open
    Session ending, handing the PCB/industrial-design track to a local
    agent with real browser access -- this session was blocked on every
    direct vendor/distributor page fetch (403s throughout, including inside
    the automated deep-research workflow), so all cost/sourcing research so
    far is search-snippet triangulation rather than verified live data.
    docs/HANDOFF.md rewritten as the current handoff (prior "executed"
    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
